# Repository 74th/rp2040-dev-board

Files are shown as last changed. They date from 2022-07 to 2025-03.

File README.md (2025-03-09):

# 74th が RP2040/RP2350 を手ではんだ付けしてみたくて作った開発ボード

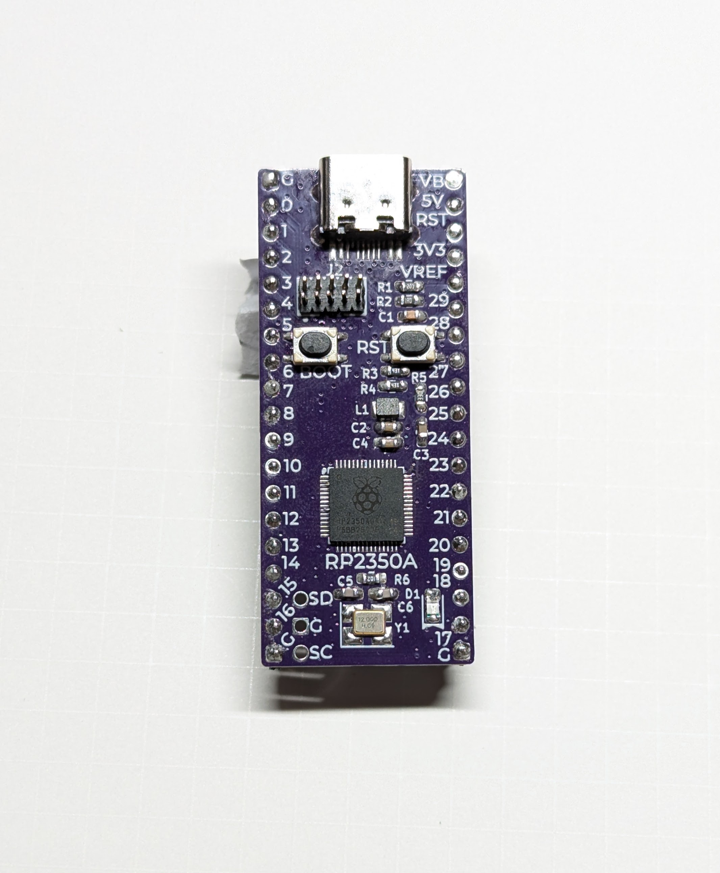
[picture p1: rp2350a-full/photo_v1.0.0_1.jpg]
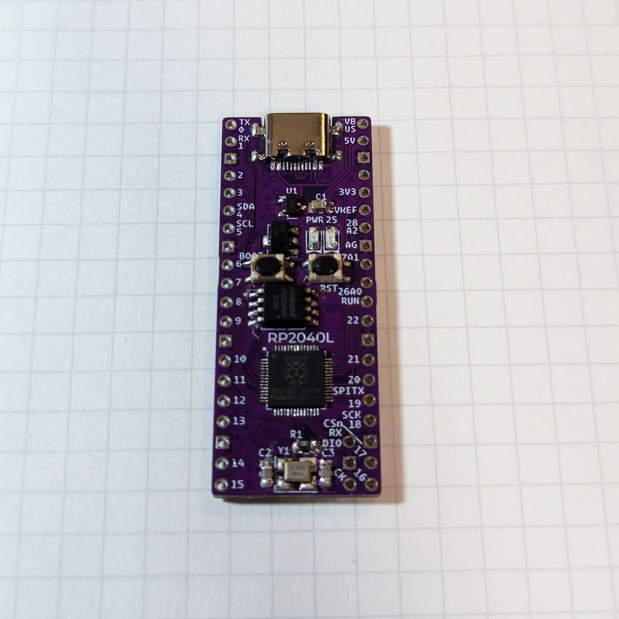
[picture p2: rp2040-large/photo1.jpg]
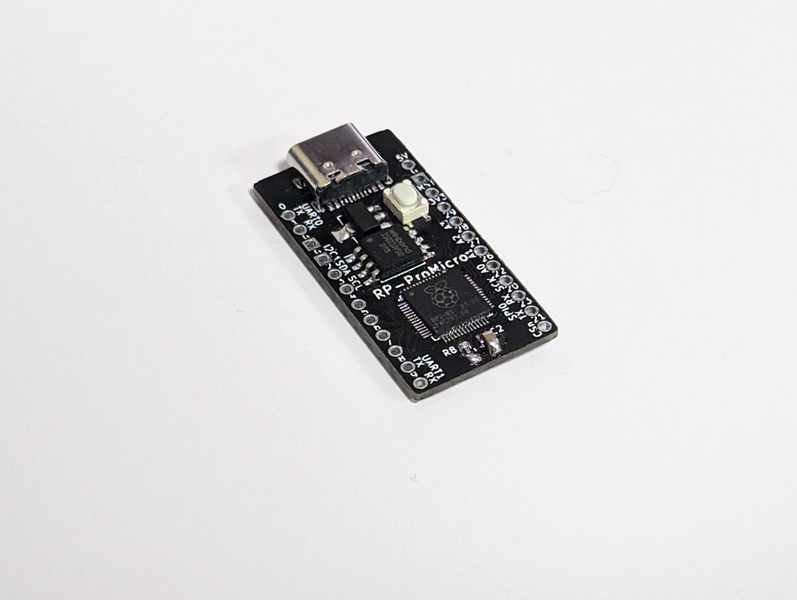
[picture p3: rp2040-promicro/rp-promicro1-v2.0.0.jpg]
  

- [Raspberry PI PICO と同じピン配置で、Flush のサイズを変えたいために、作った開発ボード rp2040 large board](./rp2040-large/)
- [ProMicro ピンアウト開発ボード rp2040 pro micro](./rp2040-promicro/)
- [RP2350の全てのピンを引き足した開発ボード（位置決め治具対応） RP2350A-Full](./rp2350a-full/)
- [RP2040の手はんだ実装支援用位置決め治具 RP2040 Solder Supporter](./rp2040-supporter/)
- [完成後のチェック用に使うファームウェア](rp2040-io-tester/) [rp2040-io-tester.uf2](rp2040-io-tester/rp2040-io-tester.uf2)
- [部品の調達先](./parts/)

## RP2040 手はんだ実装挑戦指南ガイド

74th の実装ノウハウをまとめたガイドを用意しています。初めて挑戦される方はぜひおよみください。

https://docs.google.com/document/d/1oHzV6qEClttqfrnbo-PlUElAemhTQe8-u3ijAKLZYF0/edit#heading=h.1b8zdysibsw9

## 使用しているシンボル、フットプリントライブラリ

https://github.com/74th/my-kicad-parts

## LICENSE

MIT

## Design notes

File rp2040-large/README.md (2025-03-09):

# RP2040 large board

RP2040 を手ではんだづけするのにトライしてみた開発ボードです。

Raspberry Pi PICO と同じピンレイアウトで、Flash を好きなサイズのものに置き換えて使うことができます。

RP2040 の実装の際には、細く切ったマスキングテープを使って位置合わせをしてから、実装すると成功率が上がります。

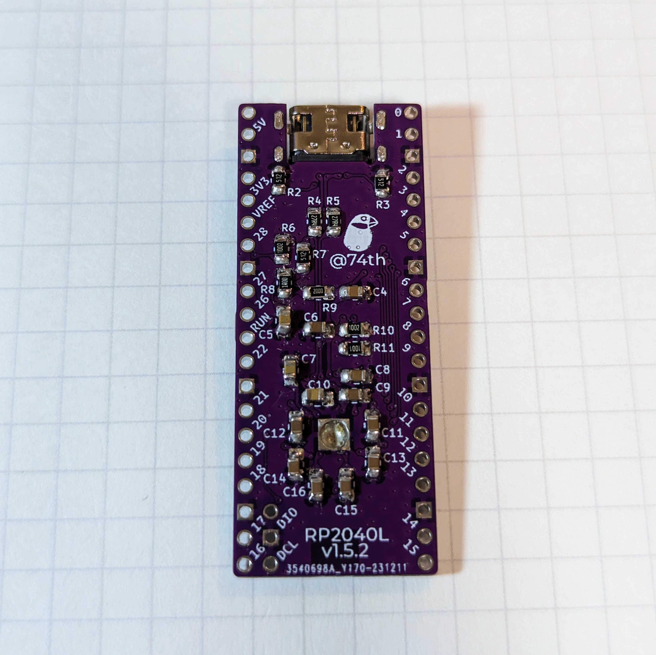
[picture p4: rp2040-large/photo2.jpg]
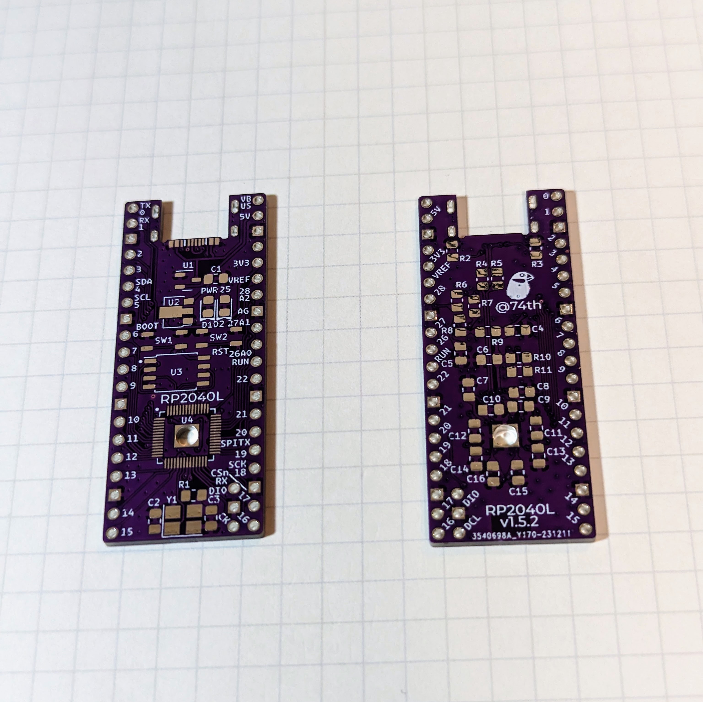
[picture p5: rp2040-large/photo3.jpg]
  

## v1.5.2

- 回路図 [PDF](./rp2040-large-semantics-1.5.2.pdf) [kicanvas](https://kicanvas.org/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)
- PCB [kicanvas](https://kicanvas.org/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)

### features

- USB 電源保護 IC として [CH213K](https://www.wch-ic.com/products/CH213.html) を追加

### BOM

| Reference | Name | Quantity |
| --- | --- | --- |
| C1, C4 | Capacitor 0805 10uF | 2 |
| C2, C3 | Capacitor 0805 10-33pF | 2 |
| C5, C7, C10 | Capacitor 0805 1uF | 3 |
| C6, C8, C9, C11-C16 | Capacitor 0805 100nF | 9 |
| D1 | LED 0805 RED | 1 |
| D2 | LED 0805 BLUE | 1 |
| J1 | USB Type-C Receptacle | 1 |
| R1, R11 | Resistor 0805 1kΩ | 2 |
| R2, R3, R7 | Resistor 0805 5.1kΩ | 3 |
| R4, R5 | Resistor 0805 27Ω | 2 |
| R6, R10 | Resistor 0805 10kΩ | 2 |
| R8 | Resistor 0805 1RΩ | 1 |
| R9 | Resistor 0805 200Ω | 1 |
| SW1, SW2 | Button SKRPABE010 | 2 |
| U1 | USB Power Protection IC SOT-23 CH213K | 1 |
| U2 | Regulator 3.3V SOT-89 AMS1117-3.3 | 1 |
| U3 | Flash SOIC-8 W25Q32JVS | 1 |
| U4 | MCU Raspberry Pi RP2040 | 1 |
| Y1 | Crystal 3225 12MHz | 1 |

### BOM

## v1.4.0

- 回路図 [PDF](./rp2040-large-semantics-1.4.0.pdf) [kicanvas](https://kicanvas.org/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)
- PCB [kicanvas](https://kicanvas.org/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)

| ID | package | Value | Num |
| --- | --- | --- | --- |
| C1,C2,C4,C6-C8,C10,C13,C16 | 0805in 2012mm SMD Capacitor | 100nF | 9 |
| C3,C5,C9 | 0805in 2012mm SMD Capacitor | 1uF | 3 |
| C11,C12 | 0603in 1608mm SMD Capacitor | 27pF | 2 |
| C14,C15 | 0805in 2012mm SMD Capacitor | 10uF | 2 |
| R1,R2 | 0805in 2012mm SMD Resistor | 27.4R | 2 |
| R3,R6 | 0805in 2012mm SMD Resistor | 1kR | 2 |
| R7 | 0805in 2012mm SMD Resistor | 1kR(NC) | 1 |
| R4,R5 | 0805in 2012mm SMD Resistor | 5.1kR | 2 |
| R8 | 0805in 2012mm SMD Resistor | 10kR | 1 |
| R9 | 0805in 2012mm SMD Resistor | 200R | 1 |
| R10 | 0805in 2012mm SMD Resistor | 1R | 1 |
| U1 | RP2040 | | 1 |
| U2 | W25Q32BVSSIG | | 1 |
| U3 | AMS 1117-3.3V | | 1 |
| P1 | USB 2.0 Type-C MidMount Socket | | 1 |
| Y1 | 3325mm SMD Quartz Resonator Crystal | 12MHz | 1 |
| SW1,SW2 | 3x4x2.5mm SMD Tactile Switch | | 2 |

## v1.3.1

| ID | package | Value | Num |
| --- | --- | ----- | --- |
| C1,C2,C4,C6-C8,C10,C13,C16 | 0805in 2012mm SMD Capacitor | 100nF | 9 |
| C3,C5 | 0805in 2012mm SMD Capacitor | 1uF | 2 |
| C11,C12 | 0603in 1608mm SMD Capacitor | 27pF  | 2 |
| C14,C15 | 0805in 2012mm SMD Capacitor | 10uF  | 2 |
| R1,R2 | 0805in 2012mm SMD Resistor | 27.4R | 2 |
| R3,R6,R7 | 0805in 2012mm SMD Resistor | 1kR | 2 |
| R4,R5 | 0805in 2012mm SMD Resistor | 5.1kR | 2 |
| R8 | 0805in 2012mm SMD Resistor | 10kR  | 1 |
| U1 | RP2040 | | 1 |
| U2 | W25Q32BVSSIG | | 1 |
| U3 | AMS 1117-3.3V | | 1 |
| P1 | USB 2.0 Type-C MidMount Socket | | 1 |
| Y1 | 3325mm SMD Quartz Resonator Crystal | 12MHz | 1 |

## 部品の購入先

[../parts/README.md](../parts/README.md)

## RP2040 手はんだ実装挑戦指南ガイド

74th の実装ノウハウをまとめたガイドを用意しています。初めて挑戦される方はぜひおよみください。

https://docs.google.com/document/d/1oHzV6qEClttqfrnbo-PlUElAemhTQe8-u3ijAKLZYF0/edit#heading=h.1b8zdysibsw9

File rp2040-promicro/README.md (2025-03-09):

# RP2040 Pro Micro ピンアウト開発ボード \[74th-012\]

発注用ガーバーファイルは [release page](https://github.com/74th/rp2040-dev-board/releases) を確認ください。

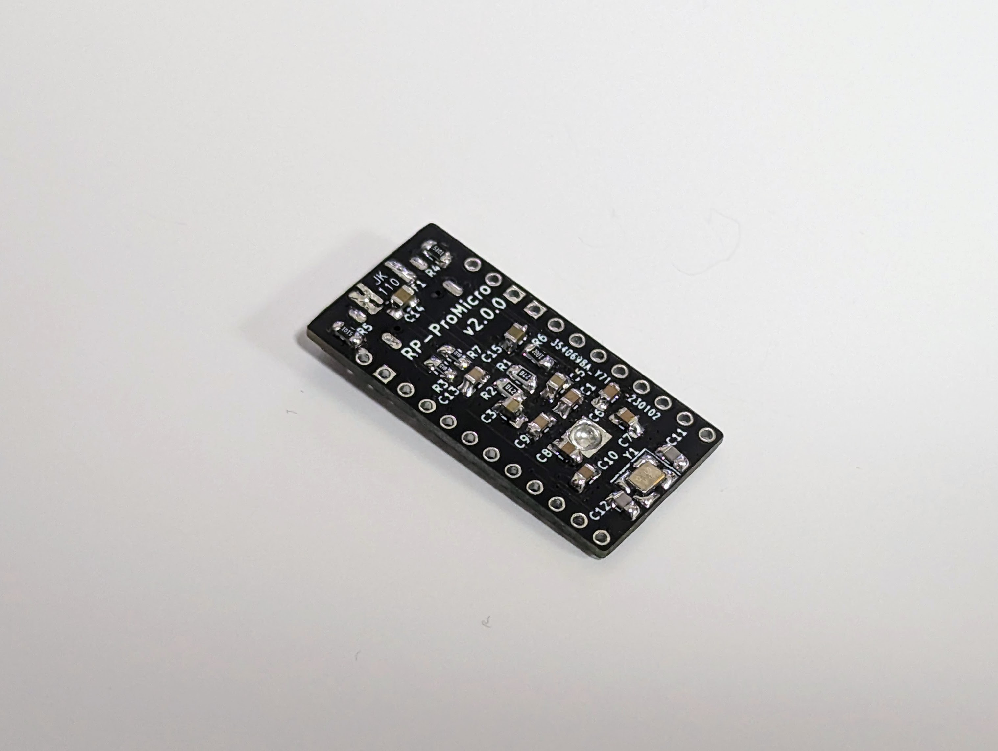
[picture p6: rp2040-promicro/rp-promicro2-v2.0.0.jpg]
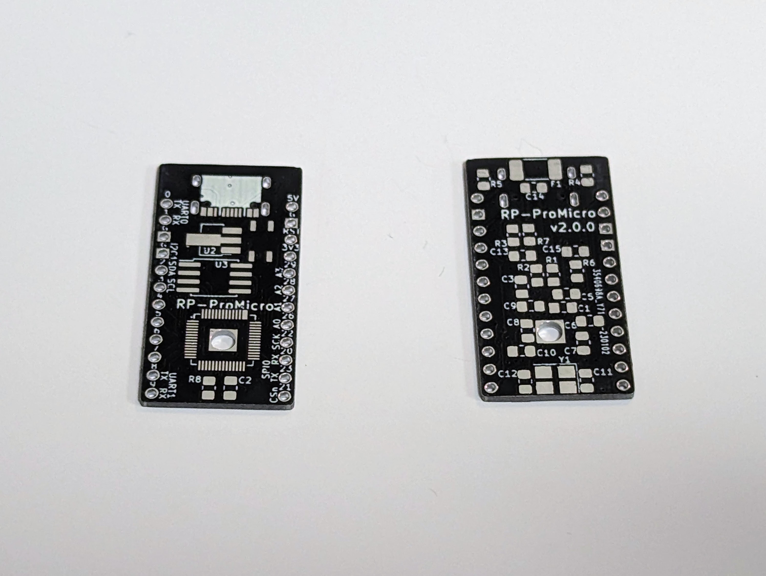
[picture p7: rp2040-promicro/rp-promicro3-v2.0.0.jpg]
  

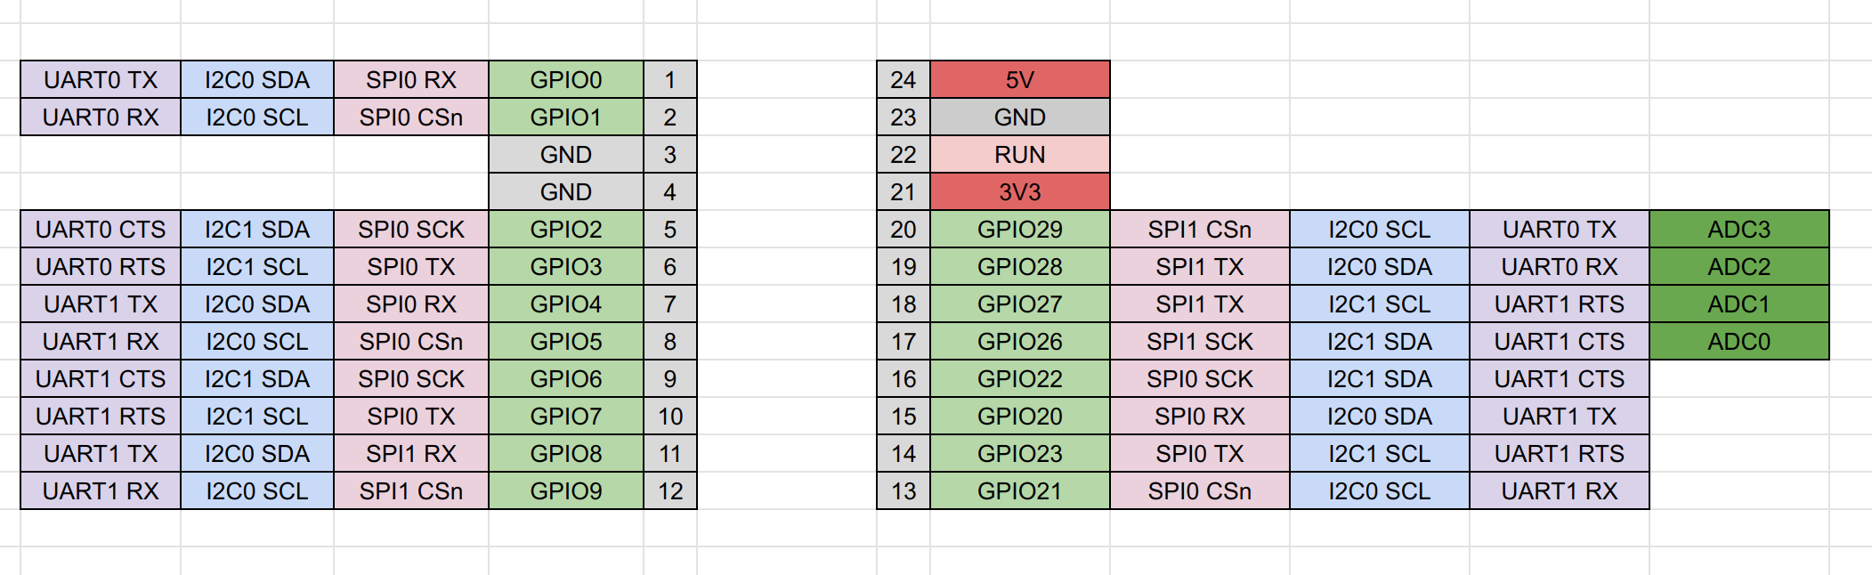
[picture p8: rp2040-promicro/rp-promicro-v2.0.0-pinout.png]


- Booth キット販売ページ [https://74th.booth.pm/items/4492441](https://74th.booth.pm/items/4492441)

## 2.0.1-2

2.0.2 は KiCad 8.0 で出力し直したもので、2.0.1 と差異はありません。

- 回路図: [PDF](rp2040-promicro-v2.0.1-semantics.pdf) [kicanvas](https://kicanvas.org/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)
- PCB 2.0.1 [kicanvas](https://kicanvas.org/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)
- PCB 2.0.2 [kicanvas](https://kicanvas.org/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)

| Reference | Name | Quantity |
| --- | --- | --- |
| C1, C4, C7-C12 | Capacitor 0805 100nF | 8 |
| C2, C3 | Capacitor 0805 10uF | 2 |
| C5, C6 | Capacitor 0805 1uF | 2 |
| C13, C14 | Capacitor 0805 10-27pF | 2 |
| F1 | PolyFuse 1812 KT6-1100SMDI | 1 |
| J1 | USB Type-C Receptacle | 1 |
| R1, R4, R5 | Resistor 0805 1kΩ | 3 |
| R2, R3 | Resistor 0805 5.1kΩ | 2 |
| R6 | Resistor 0805 10kΩ | 1 |
| R7, R8 | Resistor 0805 10-27Ω | 2 |
| SW1 | Button SKRPABE010 | 1 |
| U1 | Regulator 3.3V SOT-89 AMS1117-3.3 | 1 |
| U2 | Flash SOIC-8 W25Q128JVS | 1 |
| U3 | MCU Raspberry Pi RP2040 | 1 |
| Y1 | Crystal 3225 12MHz | 1 |

※ 大変申し訳ありません。2023/09/17 まで誤った部品表が 2.0.1 として掲載されておりました。

## 2.0.0

- 回路図: [PDF](rp2040-promicro-v2.0.0-semantics.pdf) [kicanvas](https://kicanvas.org/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)
- PCB [PDF](rp2040-promicro-v2.0.0-pcb.pdf) [kicanvas](https://kicanvas.org/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)

| Designator | Parts | Quantity |
| --- | --- | --- |
| R1, R2 | 0805 レジスタ 27.4R | 2 |
| R3, R7, R8 | 0805 レジスタ 1kR | 3 |
| R4, R5 | 0805 レジスタ 5.1kR | 2 |
| R6 | 0805 レジスタ 10kR | 1 |
| C1, C2, C6, C7, C8, C9,C10, C13 | 0805 キャパシタ 100nF | 8 |
| C11, C12 | 0805 キャパシタ 27pF | 2 |
| C14, C15 | 0805 キャパシタ 10uF | 2 |
| C3, C5 | 0805 キャパシタ 1uF | 2 |
| F1 | リセッタブルフィーズ KT6-1100SMDI | 1 |
| J1 | USB Type-C ソケット | 1 |
| J2 | ピンヘッダー(ProMicro Left) | 1 |
| J3 | ピンヘッダー(ProMicro Left) | 1 |
| SW1 | SKRPABE010 | 1 |
| U1 | MCU RP2040 | 1 |
| U2 | FLASH W25Q32JVS | 1 |
| U3 | レギュレータ AMS1117(SOT-89) | 1 |
| Y1 | クリスタル 12MHz 3225 | 1 |

## v1.1.0

- 回路図 [rp2040-promicro-v1.1.0-semantics.pdf](rp2040-promicro-v1.1.0-semantics.pdf)
- PCB [rp2040-promicro-v1.1.0-pcb.pdf](rp2040-promicro-v1.1.0-pcb.pdf)

### 部品表

| Item | Qty | Reference(s) | Value | LibPart | Footprint | Datasheet |
| ---- | --- | --- | --- | --- | --- | --- |
| 1 | 9 | C1, C2, C4, C6, C7, C8, C9, C10, C13 | 100nF | Device:C | rp2040-dev-board:Capacitor_0805_2012 | ~ |
| 2 | 2 | C3, C5 | 1uF | Device:C | rp2040-dev-board:Capacitor_0805_2012 | ~ |
| 3 | 2 | C11, C12 | 27pF | Device:C | rp2040-dev-board:Capacitor_0603_1608 | ~ |
| 4 | 2 | C14, C15 | 10uF | Device:C | rp2040-dev-board:Capacitor_0805_2012 | ~ |
| 5 | 1 | J2 | ProMicro-LeftPin  | rp2040-dev-board:ProMicro-LeftPin  | rp2040-dev-board:LeftPin | |
| 6 | 1 | J3 | ProMicro-RightPin | rp2040-dev-board:ProMicro-RightPin | rp2040-dev-board:RightPin | |
| 7 | 1 | P1 | USB2.0_C_12pin | rp2040-dev-board:USB2.0_C_12pin | rp2040-dev-board:USB-C-12-Pin-MidMount-ali-v2 | https://www.usb.org/sites/default/files/documents/usb_type-c.zip |
| 8 | 2 | R1, R2 | 27.4R | Device:R | rp2040-dev-board:Resistor_0805_2012 | ~ |
| 9 | 2 | R3, R7 | 1kR | Device:R | rp2040-dev-board:Resistor_0805_2012 | ~ |
| 10 | 2 | R4, R5 | 5.1kR | Device:R | rp2040-dev-board:Resistor_0805_2012 | ~ |
| 11 | 1 | R6 | 10kR | Device:R | rp2040-dev-board:Resistor_0805_2012 | ~ |
| 12 | 1 | SW1 | SW_Push | Switch:SW_Push | rp2040-dev-board:BOOT | ~ |
| 13 | 1 | U1 | RP2040 | rp2040-dev-board:RP2040 | rp2040-dev-board:RP2040_hand | |
| 14 | 1 | U2 | W25Q128JVS | Memory_Flash:W25Q128JVS | rp2040-dev-board:W25Q16-128JV-SOIC | http://www.winbond.com/resource-files/w25q128jv_dtr%20revc%2003272018%20plus.pdf |
| 15 | 1 | U3 | AZ1117-3.3 | Regulator_Linear:AZ1117-3.3 | rp2040-dev-board:Regulator-AMS1117-SOT-223 | https://www.diodes.com/assets/Datasheets/AZ1117.pdf |
| 16 | 1 | Y1 | Crystal_GND24 | Device:Crystal_GND24 | Crystal:Crystal_SMD_3225-4Pin_3.2x2.5mm_HandSoldering | ~ |

## RP2040 手はんだ実装挑戦指南ガイド

74th の実装ノウハウをまとめたガイドを用意しています。初めて挑戦される方はぜひおよみください。

https://docs.google.com/document/d/1oHzV6qEClttqfrnbo-PlUElAemhTQe8-u3ijAKLZYF0/edit#heading=h.1b8zdysibsw9

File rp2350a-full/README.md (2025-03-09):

# RP2350A 手はんだ実装挑戦ボード

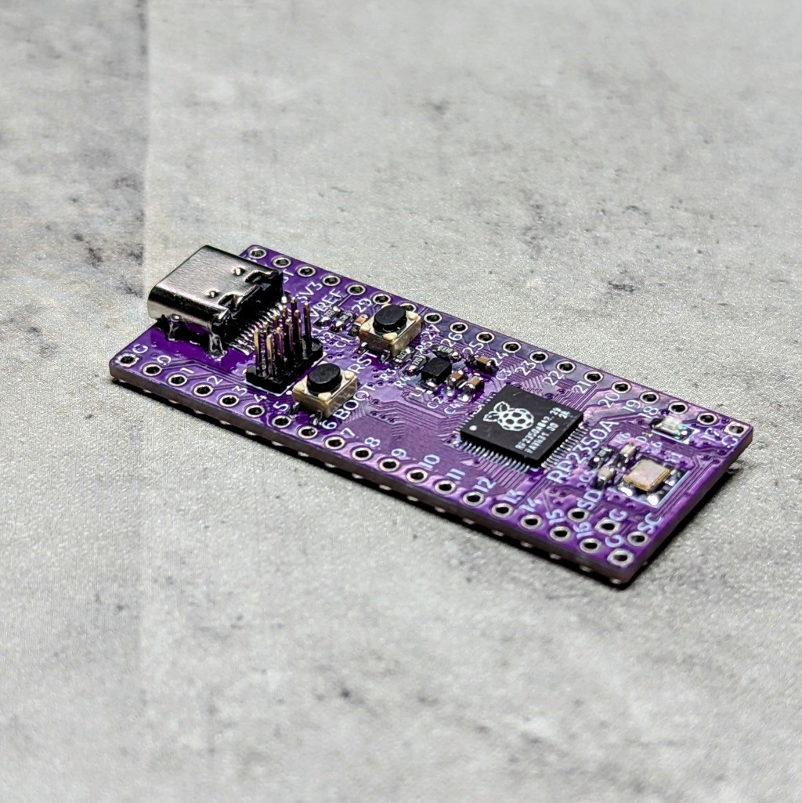
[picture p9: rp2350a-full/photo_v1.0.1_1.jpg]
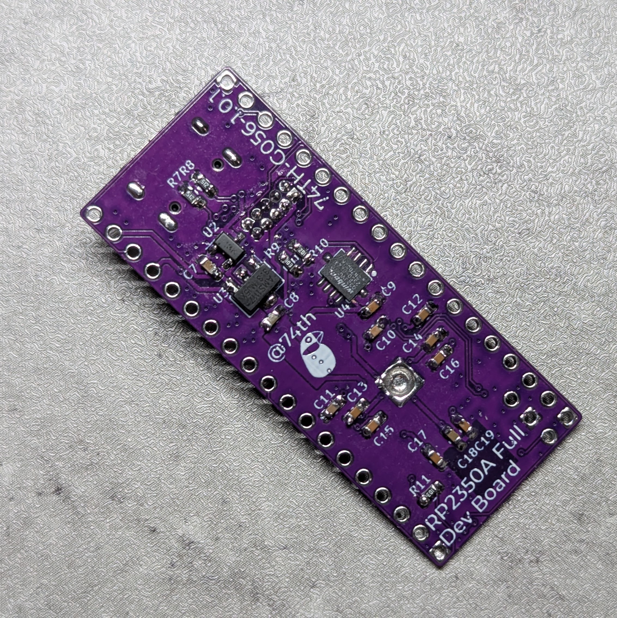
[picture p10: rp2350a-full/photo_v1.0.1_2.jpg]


## v1.0.1

- 回路図 [PDF](./rp2350a-full_v1.0.1_semantics.pdf) [kicanvas](https://kicanvas.org/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)
- PCB [kicanvas](https://kicanvas.org/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)

### Pin Map

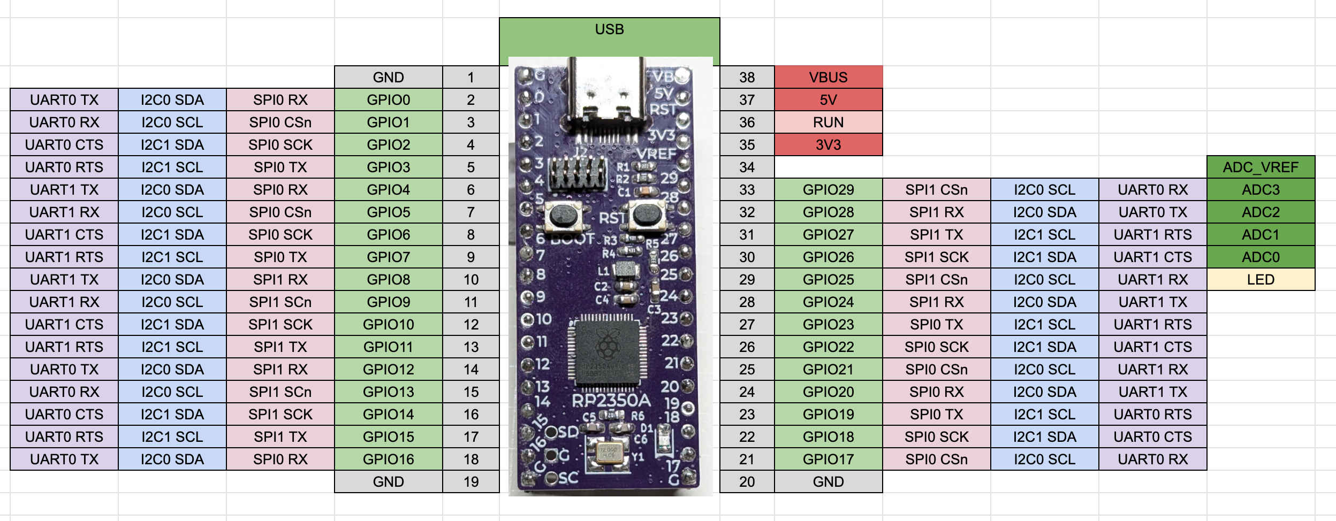
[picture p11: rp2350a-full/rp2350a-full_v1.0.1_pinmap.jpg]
Pin Map


### BOM

| Reference | Name | Package | Quantity |
| --- | --- | --- | --- |
| C1,C9-17,C19 | Capacitor 0.1uF | SMD I0603 M1608 | 11 |
| C2-4,C18 | Capacitor 4.7uF | SMD I0603 M1608 | 4 |
| C5-6 | Capacitor 7-33pF | SMD I0603 M1608 | 2 |
| C7-8 | Capacitor 10uF | SMD I0603 M1608 | 2 |
| D1 | LED Blue | SMD I0805 M2012 | 1 |
| J1 | USB Type-C Receptacle | | 1 |
| J2 | Box Pin Header 2x5 Pitch 1.27mm | TH | 1 |
| L1 | Inductor 3.3uH | SMD I0806 M2016 | 1 |
| R1 | Resistor 200Ω | SMD I0603 M1608 | 1 |
| R2 | Resistor 1Ω | SMD I0603 M1608 | 1 |
| R3-4 | Resistor 27Ω | SMD I0603 M1608 | 2 |
| R5 | Resistor 33Ω | SMD I0603 M1608 | 1 |
| R6,R10 | Resistor 1kΩ | SMD I0603 M1608 | 2 |
| R7-8 | Resistor 5.1kΩ | SMD I0603 M1608 | 2 |
| R9,R11 | Resistor 10kΩ | SMD I0603 M1608 | 2 |
| SW1-2 | Button SKRPABE010 | | 2 |
| U1 | MCU Raspberry Pi RP2350A | QFN56 | 1 |
| U2 | USB Power Protection IC CH213K | SOT-23 | 1 |
| U3 | Regulator 3.3V SOT-89 AMS1117-3.3 | SOT-90 | 1 |
| U4 | Flash W25Q32JVUU | USON-8 | 1 |
| Y1 | Crystal 12MHz | SMD 3225 | 1 |

## 実装の手順

実装したときの記録を記事にしています。こちらを実装前に参考にお読みいただけると良いかと思います。

https://74th.hateblo.jp/entry/2025/01/12/222618

かならずフラックスを用意してください。ブリッジした場合にはフラックスを塗って、はんだごてをあてて余分なフラックスを取り除きましょう。

以下の順序で実装することを推奨しています。

1. RP2350A(U1): RP2040 用の[位置決めボード](https://74th.booth.pm/items/5573498)を使えるなら使いましょう。手はんだ実装時のノウハウは
   https://docs.google.com/document/d/1oHzV6qEClttqfrnbo-PlUElAemhTQe8-u3ijAKLZYF0/edit#heading=h.1b8zdysibsw9 にまとめています。
2. USB Type-C: 受動部品実装前の方が、ランドを用いた疎通チェックがやりやすいため。[実装チェックツール](https://74th.booth.pm/items/5812941)を使うと便利です。
3. DCDC 用インダクタ(L1): 付近に囲むように他の部品があるため、先に実装します。
4. W25Q32VSS(U4): 裏面パッドに流すためのランドがあり、その付近に受動部品があり、後から実装が難しいため。
   - 裏面パッドのランドは他の部分より熱が伝わりにくいです。はんだが吸い込まれるまで、十分に加熱してください。
5. AMS1117-3.3(U3): 近くに CH213 があり、実装しにくいため。
6. CH213(U2)
7. 他の抵抗(R1-11)、キャパシタ(C1-19)、水晶発振器(Y1)、LED(D1)
8. スイッチ(SW1-2): サイズが大きく他の部品の実装の邪魔になるため、後から実装する

確認して実装ミスがなさそうであれば、電気的なチェックに進みましょう。

1. VBUS(VB)、5V、3V3、GND(G)間それぞれの抵抗値を計測し、短絡している（0Ω）となっている事がないことを確認する
2. USB を接続し、5V、3V3 と GND 間の電圧を測り、それぞれの電圧が正常であることを確認する
3. L1 と GND 間の電圧を測り、1.1V が出ていることを確認する。
4. PC に USB が認識されるか確認する。

全てのピンが実装できている稼働を確認するファームウェアを作っています。

各ピンが実装漏れている、若しくはブリッジしているのを確認するファームウェアを作っています。

https://github.com/74th/mcu-pin-check-firmware/

以下がファームウェアへのダイレクトリンクです。

https://github.com/74th/mcu-pin-check-firmware/raw/refs/heads/main/release/rp2350.uf2

GNDとジャンパをつなぎ、開発ボードの各スルーホールにジャンパのもう片方でタッチします。すると、USB CDCにてGPIO 8: L、GPIO 8: Hと出力されます。
これにて、全てのピンが接続され、ブリッジされていないことを確認してください。

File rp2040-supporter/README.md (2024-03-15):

# 汎用 RP2040 手はんだ実装サポート治具

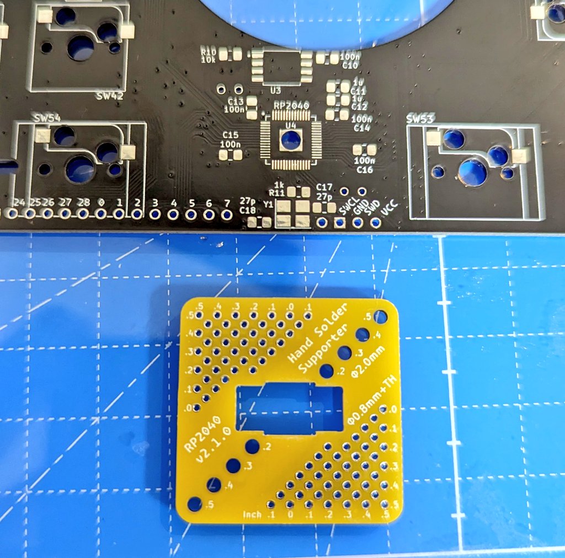
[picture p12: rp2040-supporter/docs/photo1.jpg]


RP2040 を手はんだ実装するときに部品がずれないようにピンヘッダで固定する治具です。

この治具のおかげで、0.4mm ピッチの実装を簡単に行うことができます。

このディレクトリには、使い方の README（このファイル）と、KiCad での設計ファイルが含まれています。

## 使い方

RP2040 のフットプリントは、このリポジトリにある [rp2040-dev-board.pretty/RP2040_hand.kicad_mod](../rp2040-dev-board.pretty/RP2040_hand.kicad_mod) を使用して、裏からサーマルパッドにはんだ付けできるものを利用してください。

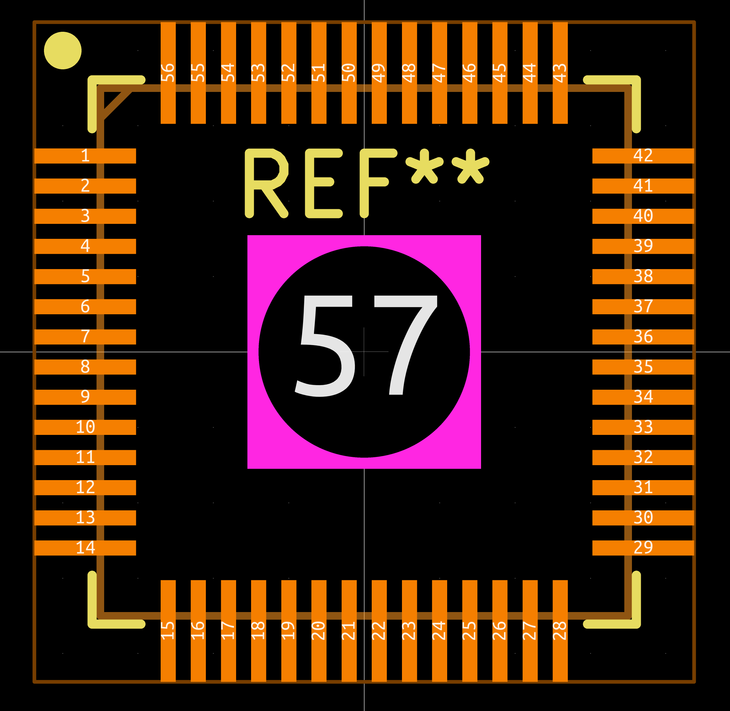
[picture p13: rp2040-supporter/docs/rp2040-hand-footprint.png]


治具には、中心から縦、横それぞれ 0.05 インチ単位で 0.20~0.50 インチ（1.27mm 単位で 5.08mm から 12.70mm）離れたとこにピンヘッダの固定用の穴が空いています。

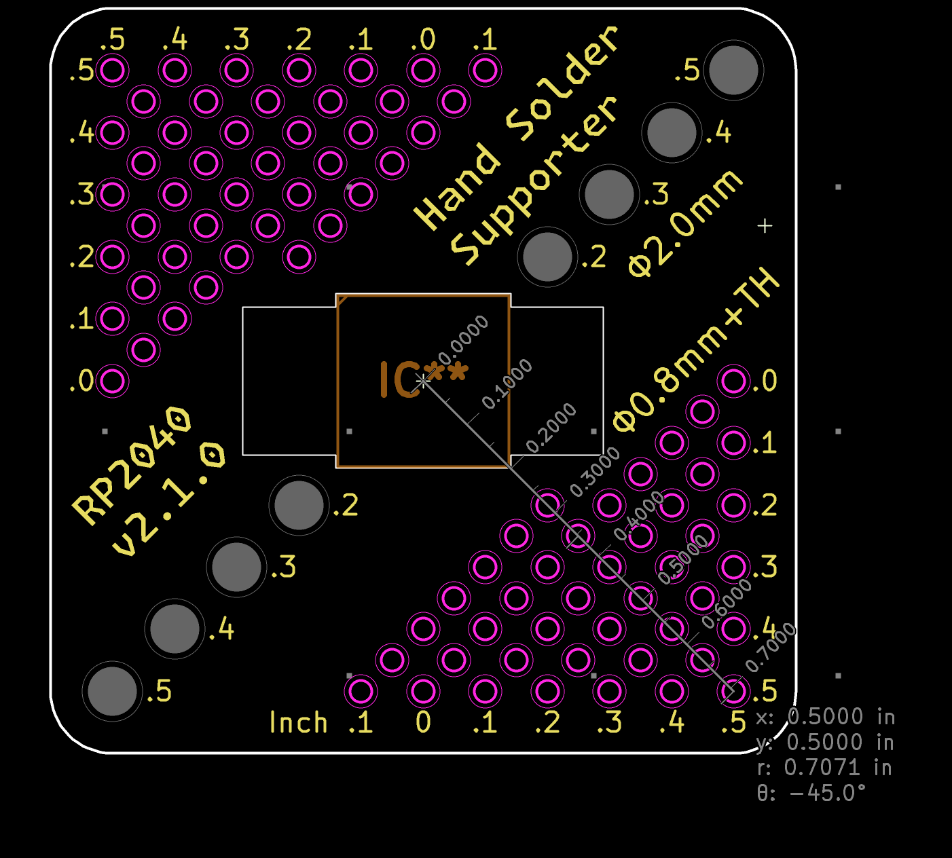
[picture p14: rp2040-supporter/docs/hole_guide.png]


これらの穴を使うように、RP2040 のまわりに 4 点スルーホールを設けます。以下は 1 つの例です。

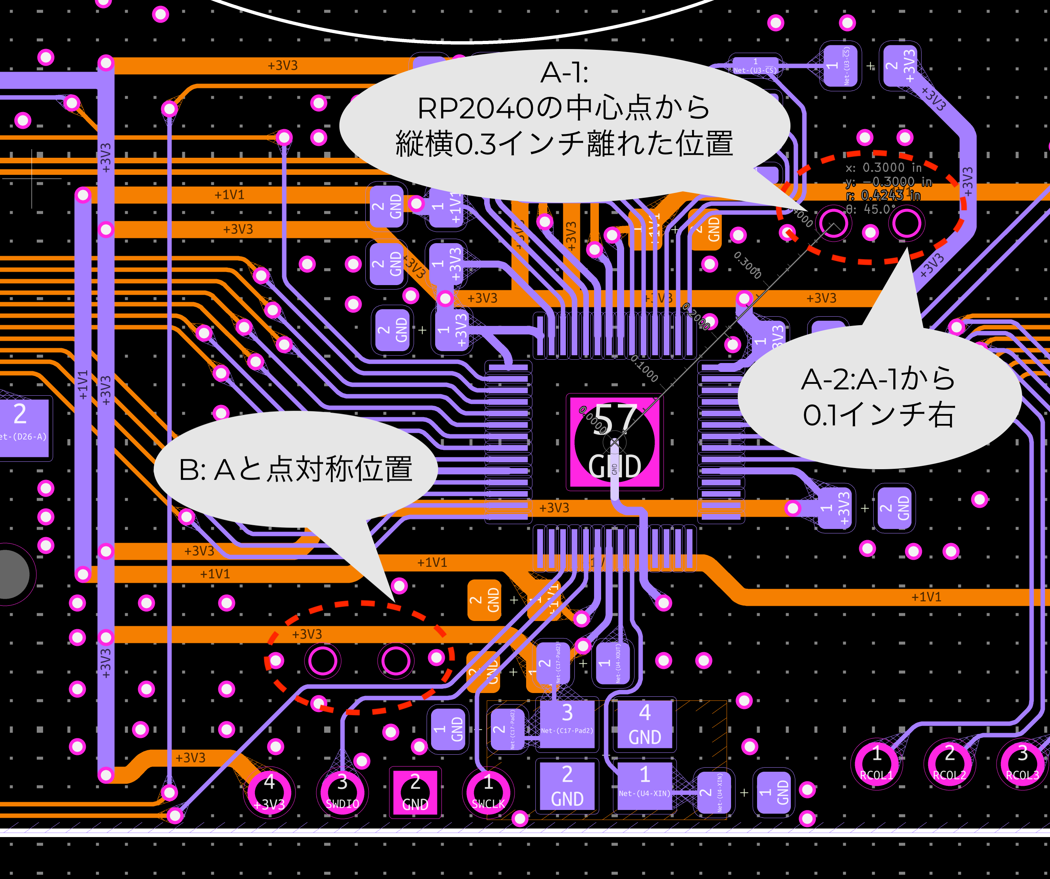
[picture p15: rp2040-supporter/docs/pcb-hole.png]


スルーホールの使用は以下のようにします。

- 穴の直径 0.8mm
- パット直径 1.0mm

実装時には 0.65mm ピンヘッダを通して配置し、RP2040 を治具にセットして、横側だけをはんだ付けします。この時にはブリッジは気にしないではんだ付けしてください。

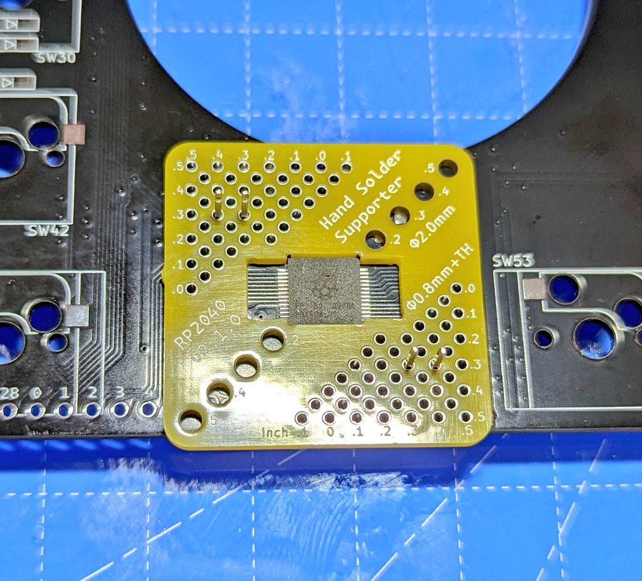
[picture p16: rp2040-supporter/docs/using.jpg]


> [!CAUTION]
> 治具を取り外す時にはかならず RP2040 を押さえつけながら行ってください。無理に外すと、治具が押さえつける力が強くて、パターンごと剥がれる場合があります。

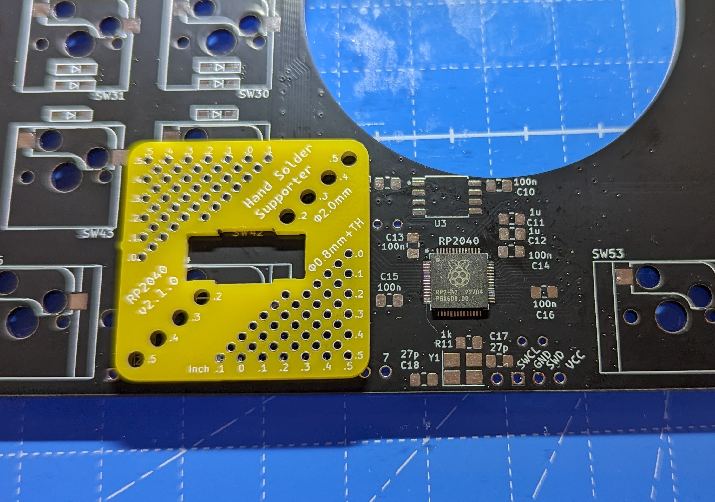
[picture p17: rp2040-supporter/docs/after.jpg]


あとは、フラックスをながしてはんだごてを当てて余分なはんだを取り除いたり、残りのピンを実装したりしてください。

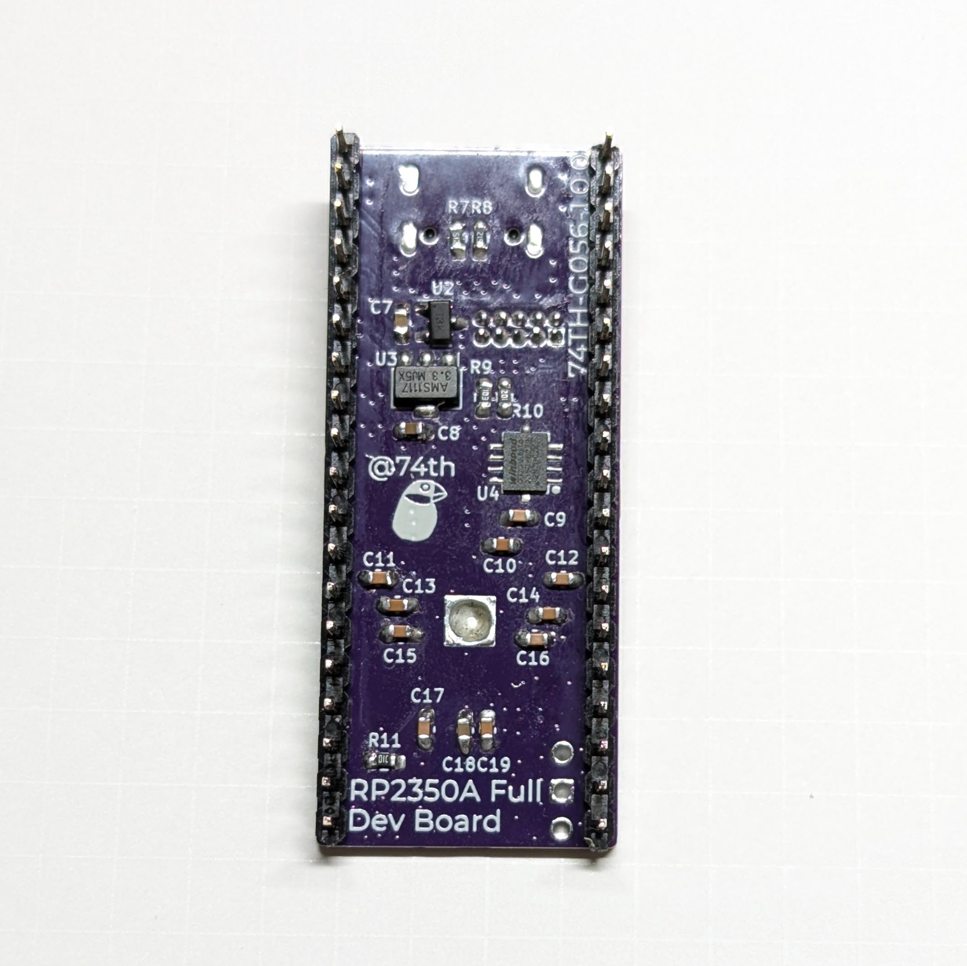
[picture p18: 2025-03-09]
rp2350a-full/photo_v1.0.0_2.jpg

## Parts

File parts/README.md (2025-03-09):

# 部品の調達先

海外サイトですが LCSC で発注をかけた方が、送料はかかりますが、お安くまとまって購入できて便利かもしれません。

☆ 印はキット同梱品の調達先

- RP2040
  - ☆ DigiKey https://www.digikey.jp/ja/products/detail/raspberry-pi/SC0914-7/14306009
  - PIMORONI https://shop.pimoroni.com/products/rp2040?variant=39345229299795
  - スイッチサイエンス https://www.switch-science.com/products/7173
  - マルツオンライン https://www.marutsu.co.jp/pc/i/2230443/
  - 秋月電子通商 https://akizukidenshi.com/catalog/g/g117056/
  - LCSC https://www.lcsc.com/product-detail/C2040.html
- SPI FLASH W25Q32JVSS
  - マルツオンライン https://www.marutsu.co.jp/pc/i/29020236/
  - DigiKey https://www.digikey.jp/ja/products/detail/winbond-electronics/W25Q32JVSSIQ/5803981
  - ☆ LCSC https://www.lcsc.com/product-detail/C179173.html
- SPI FLASH W25Q32JVUU
  - ☆ LCSC https://www.lcsc.com/product-detail/NOR-FLASH_Winbond-Elec-W25Q32JVUUIQ_C2999380.html
- 0805/2012 レジスタ
  - マルツオンライン https://www.marutsu.co.jp/pc/i/856912/
  - TaoBao https://item.taobao.com/item.htm?id=41307854370
  - ☆ LCSC: Package 0805 で絞り込んでください https://www.lcsc.com/products/Chip-Resistor-Surface-Mount_439.html
- 0805/2102 キャパシタ
  - 秋月電子通商 https://akizukidenshi.com/catalog/contents2/capnavi.aspx
  - マルツオンライン https://www.marutsu.co.jp/RatedList.jsp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
  - ☆ LCSC Package 0805 で絞り込んでください https://www.lcsc.com/products/Multilayer-Ceramic-Capacitors-MLCC-SMD-SMT_313.html
  - TaoBao https://item.taobao.com/item.htm?id=522577176099
  - TaoBao https://item.taobao.com/item.htm?id=10191700128
- 3225 クリスタル 12MHz
  - 秋月電子通商 https://akizukidenshi.com/catalog/g/g105225/
  - ☆ LCSC https://www.lcsc.com/product-detail/C9002.html など
  - AliExpress https://ja.aliexpress.com/item/1005002359133404.html
  - TaoBao https://item.taobao.com/item.htm?id=681160536821
- SOT-223 3.3V レギュレータ AMS1117（Pico 型 1.4.0 まで、ProMicro 型 1.1.0 まで）
  - ☆ AliExpress https://ja.aliexpress.com/item/4000187767118.html
  - 秋月電子通商 https://akizukidenshi.com/catalog/g/g111194/
  - LCSC https://www.lcsc.com/product-detail/Linear-Voltage-Regulators-LDO_MSKSEMI-AMS1117-3-3V_C5120796.html
  - ☆ TaoBao https://item.taobao.com/item.htm?id=35642195030
- SOT-89 3.3V レギュレータ AMS1117（Pico 型 1.5.2 以降、ProMicro 型 2.0.0 以降）
  - マルツオンライン https://www.marutsu.co.jp/pc/i/15685944/
  - Aliexpress https://ja.aliexpress.com/item/1005002037850116.html
  - LCSC https://www.lcsc.com/product-detail/C5120796.html
  - ☆ TaoBao https://item.taobao.com/item.htm?id=634687833717
- スイッチ
  - 秋月電子通商 https://akizukidenshi.com/catalog/g/g1006185/
  - ☆ LCSC https://www.lcsc.com/product-detail/C2689510.html
  - TaoBao https://item.taobao.com/item.htm?id=618991813706
  - AliExpress https://ja.aliexpress.com/item/4000555847543.html
- USB Type-C ソケット ミッドマウントタイプ（Pico 型、ProMicro 型 1.1.0 以前）
  - AliExpress https://ja.aliexpress.com/item/32998900371.html
  - マルツオンライン https://www.marutsu.co.jp/pc/i/40730718/
  - LCSC https://www.lcsc.com/product-detail/C428463.html
  - ☆ TaoBao https://item.taobao.com/item.htm?id=619399335978 (TYPEC 母座 16P 4 脚 插板 编带)
- USB Type-C ソケット 表面実装タイプ（ProMicro 型 2.0.0 以降）
  - 秋月電子通商 https://akizukidenshi.com/catalog/g/g114356/
  - LCSC https://www.lcsc.com/product-detail/C2765186.html
  - ☆ TaoBao https://item.taobao.com/item.htm?id=619399335978 (TYPEC 母座 16P 4 脚 插板 编带)
- 1812 6V 1.1A リセッタブルヒューズ（ProMicro 型 2.0.0 以降）
  - マルツオンライン https://www.marutsu.co.jp/pc/i/35540640/
  - LCSC https://www.lcsc.com/product-detail/C210834.html
  - ☆ TaoBao https://item.taobao.com/item.htm?id=555353746767
- CH213K USB 電源保護 IC、理想ダイオード（Pico 型 1.5.2 以降）
  - ☆ Aliexpress WCH Official Shop https://ja.aliexpress.com/item/1005005619632155.html?gatewayAdapt=glo2jpn
  - 秋月電子通商 https://akizukidenshi.com/catalog/g/g129462/
  - TaoBao https://item.taobao.com/item.htm?id=741731017655

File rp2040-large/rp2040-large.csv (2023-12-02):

Reference | Value | Footprint | Function | MPN | 数量
C1, C4 | 10u | 74th:Capacitor_0805_2012 |  |  | 2
C2, C3 | 27p | 74th:Capacitor_0805_2012 |  |  | 2
C5, C7, C10 | 1u | 74th:Capacitor_0805_2012 |  |  | 3
C6, C8, C9, C11-C16 | 100n | 74th:Capacitor_0805_2012 |  |  | 9
CH1 | RasperryPiPico PinOut | 74th:PinOut_RaspberryPiPico |  |  | 1
CH2 | SWD | 74th:PinOut_SWD_3Pin |  |  | 1
D1 | RED | 74th:LED_0805_2012 |  |  | 1
D2 | BLUE | 74th:LED_0805_2012 |  |  | 1
J1 | 217179-0001 | 74th:Connector_USB-C-Receptacle_SMT_12-Pin_MidMount_Simple |  |  | 1
R1, R11 | 1k | 74th:Register_0805_2012 |  |  | 2
R2, R3, R7 | 5.1k | 74th:Register_0805_2012 |  |  | 3
R4, R5 | 27.4 | 74th:Register_0805_2012 |  |  | 2
R6, R10 | 10k | 74th:Register_0805_2012 |  |  | 2
R8 | 1R | 74th:Register_0805_2012 |  |  | 1
R9 | 200 | 74th:Register_0805_2012 |  |  | 1
SW1, SW2 | SW_Push | 74th:PushButton_SKRPABE010 | -- ミックスされた値 -- |  | 2
U1 | CH213K | 74th:Package_SOT-23 |  |  | 1
U2 | AMS1117-3.3 | 74th:Package_SOT-89-3 |  |  | 1
U3 | W25Q32JVS | 74th:Package_SOIC-8_5.23x5.23mm_P1.27mm |  |  | 1
U4 | RP2040 | 74th:Package_QFN-54-1EP_7x7mm_P0.4mm_EP3.1x3.1mm_hand |  | C2040 | 1
Y1 | 12M | 74th:Crystal_SMD_3225-4Pin_3.2x2.5mm_HandSoldering |  |  | 1

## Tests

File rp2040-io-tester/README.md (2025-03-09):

GND を各ピンをつなぐと、USB CBC 経由で、どのピンに触ったかがわかって、IO の確認ができるファームウェア。

以下のリポジトリに移動しました。

https://github.com/74th/mcu-pin-check-firmware

https://github.com/74th/mcu-pin-check-firmware/tree/main/rp2040

https://github.com/74th/mcu-pin-check-firmware/blob/main/release/rp2040.uf2

https://github.com/74th/mcu-pin-check-firmware/tree/main/rp2350

https://github.com/74th/mcu-pin-check-firmware/blob/main/release/rp2350.uf2

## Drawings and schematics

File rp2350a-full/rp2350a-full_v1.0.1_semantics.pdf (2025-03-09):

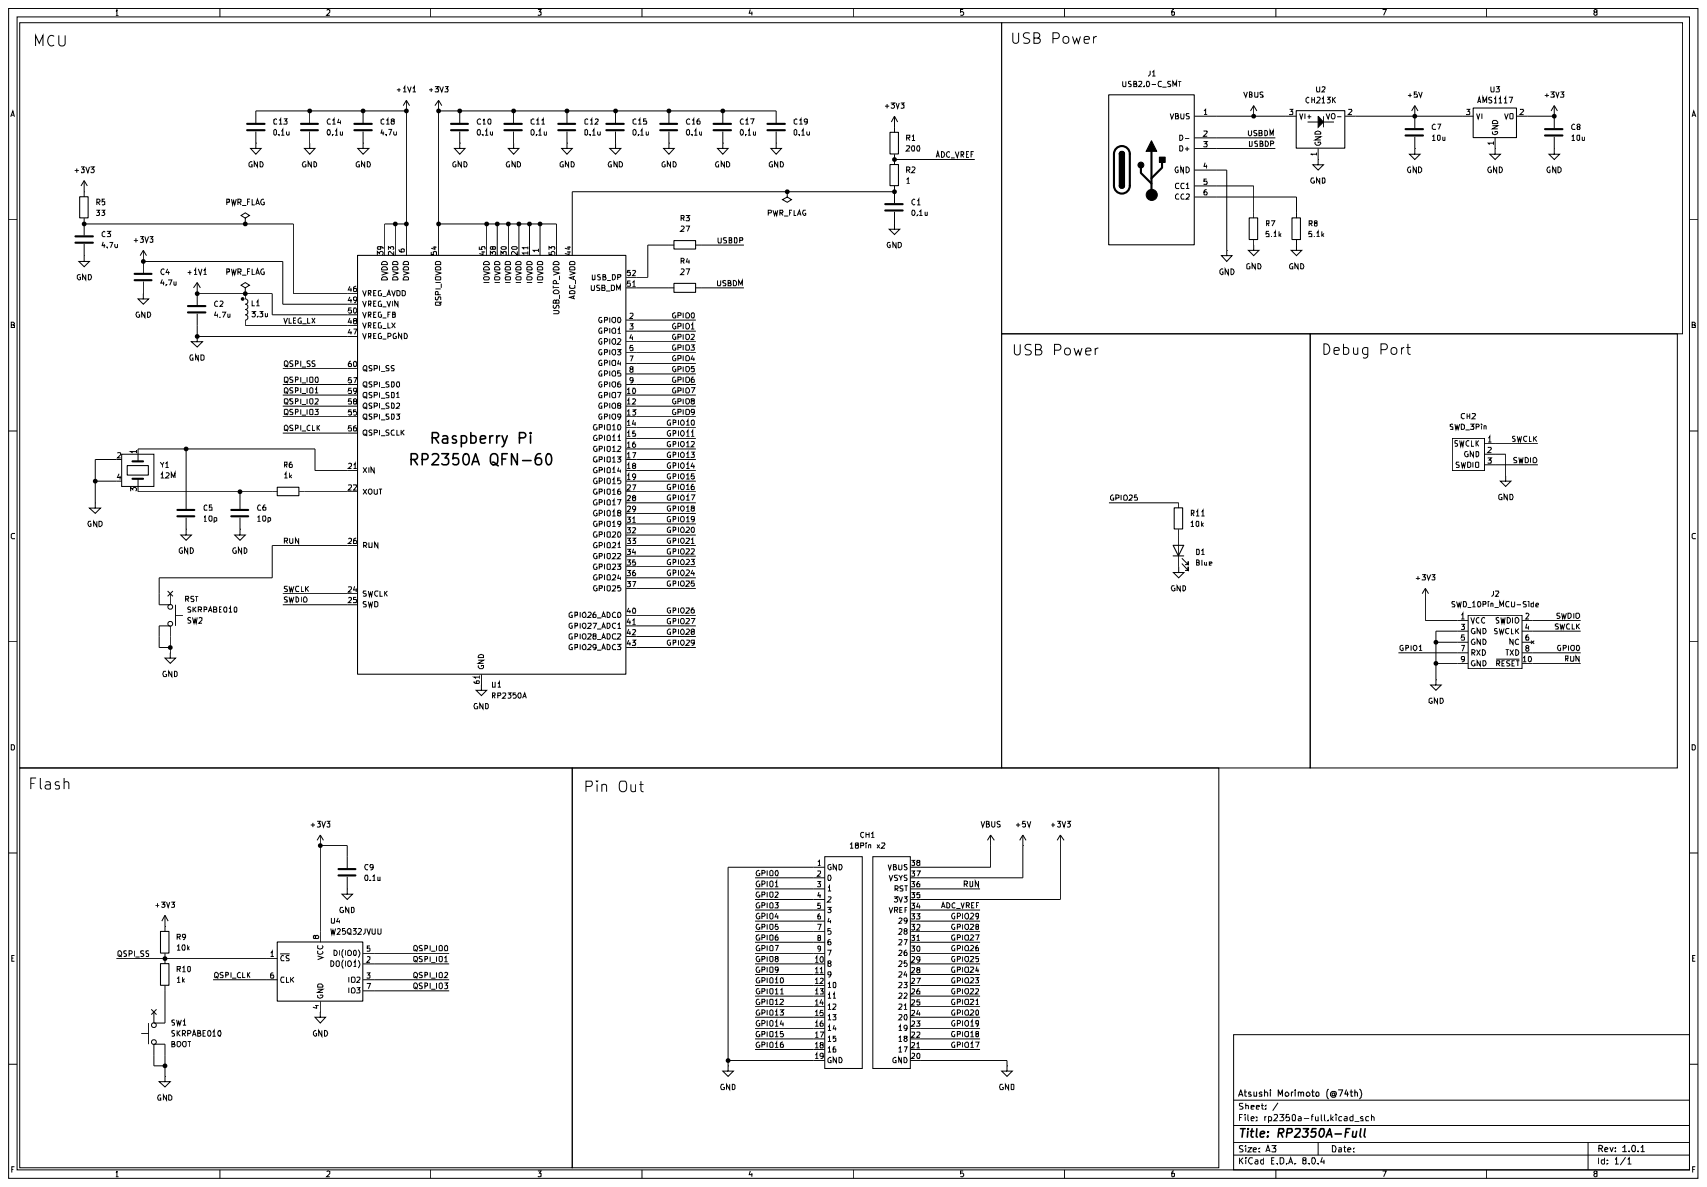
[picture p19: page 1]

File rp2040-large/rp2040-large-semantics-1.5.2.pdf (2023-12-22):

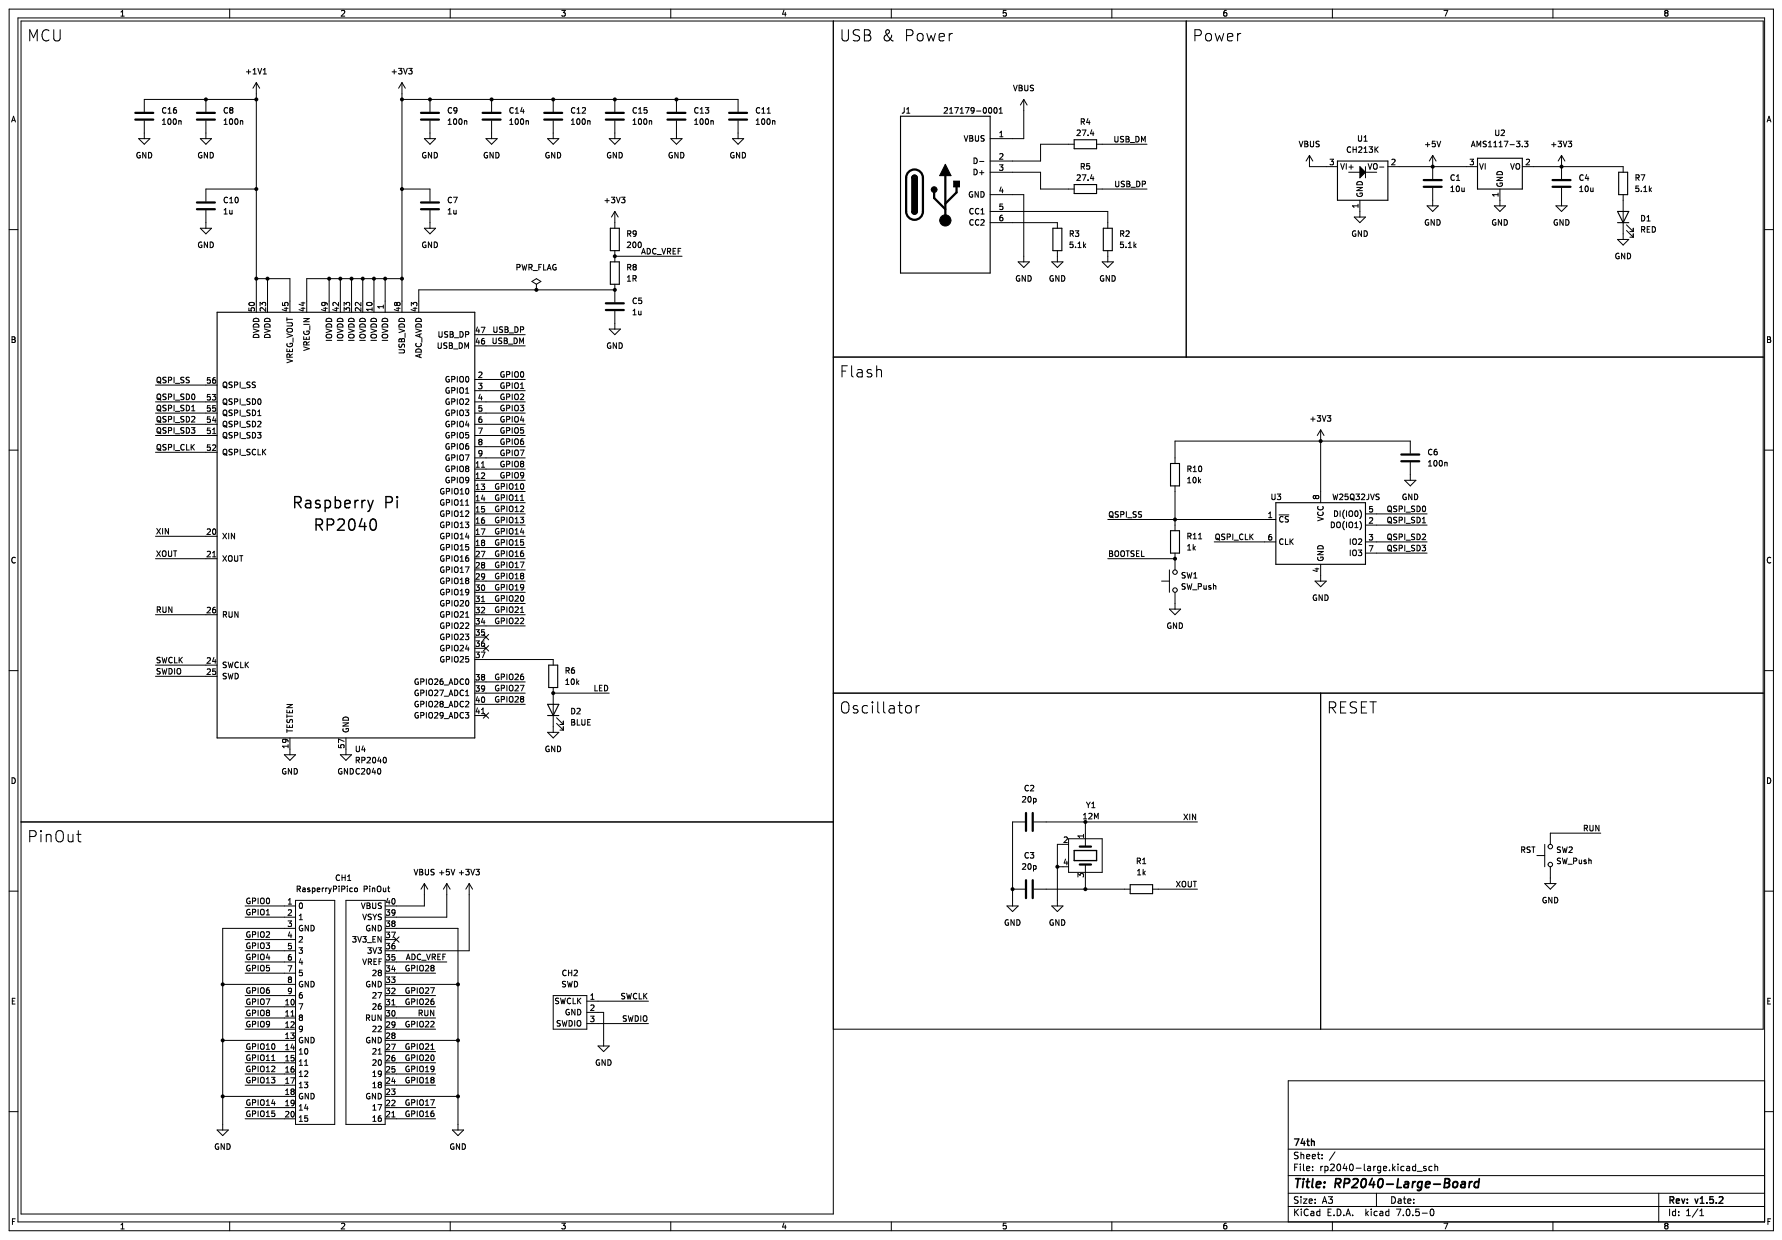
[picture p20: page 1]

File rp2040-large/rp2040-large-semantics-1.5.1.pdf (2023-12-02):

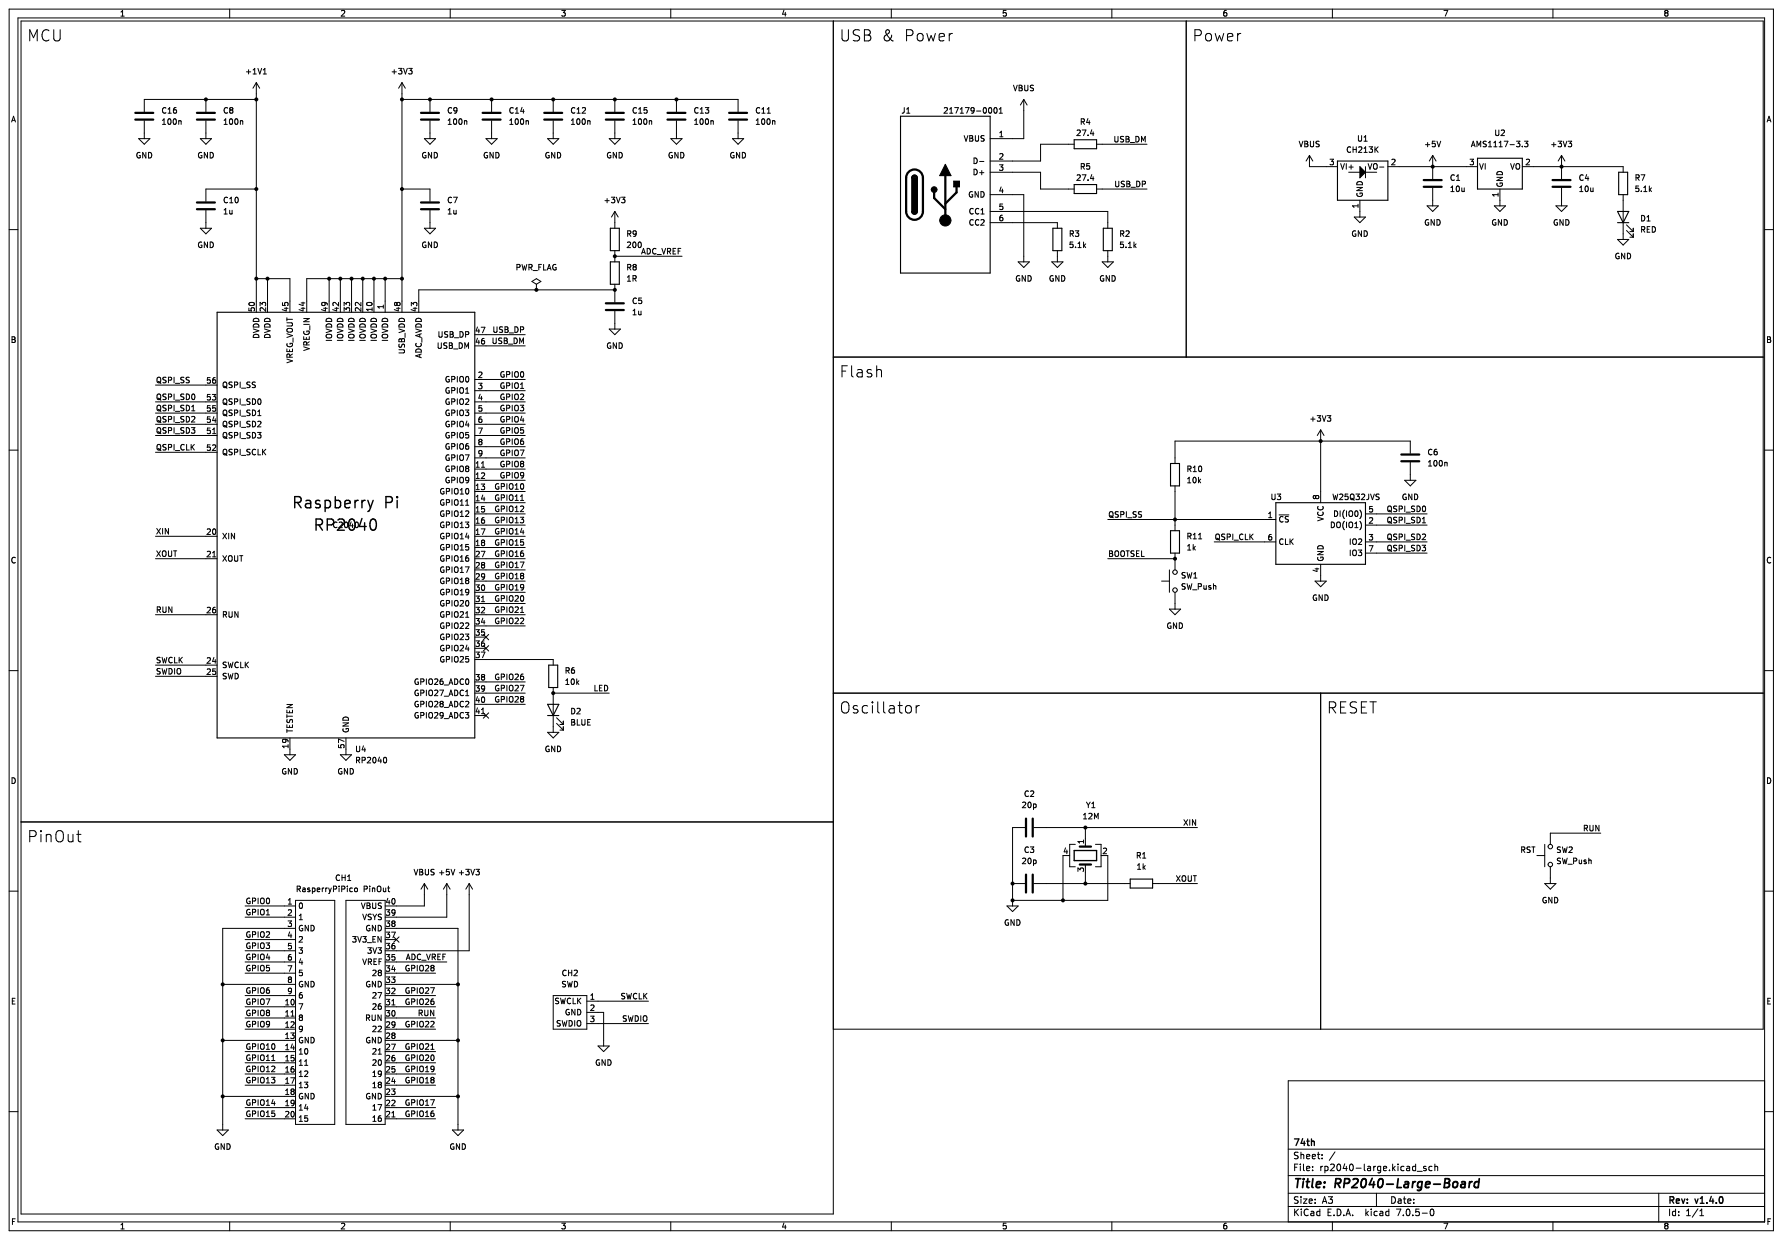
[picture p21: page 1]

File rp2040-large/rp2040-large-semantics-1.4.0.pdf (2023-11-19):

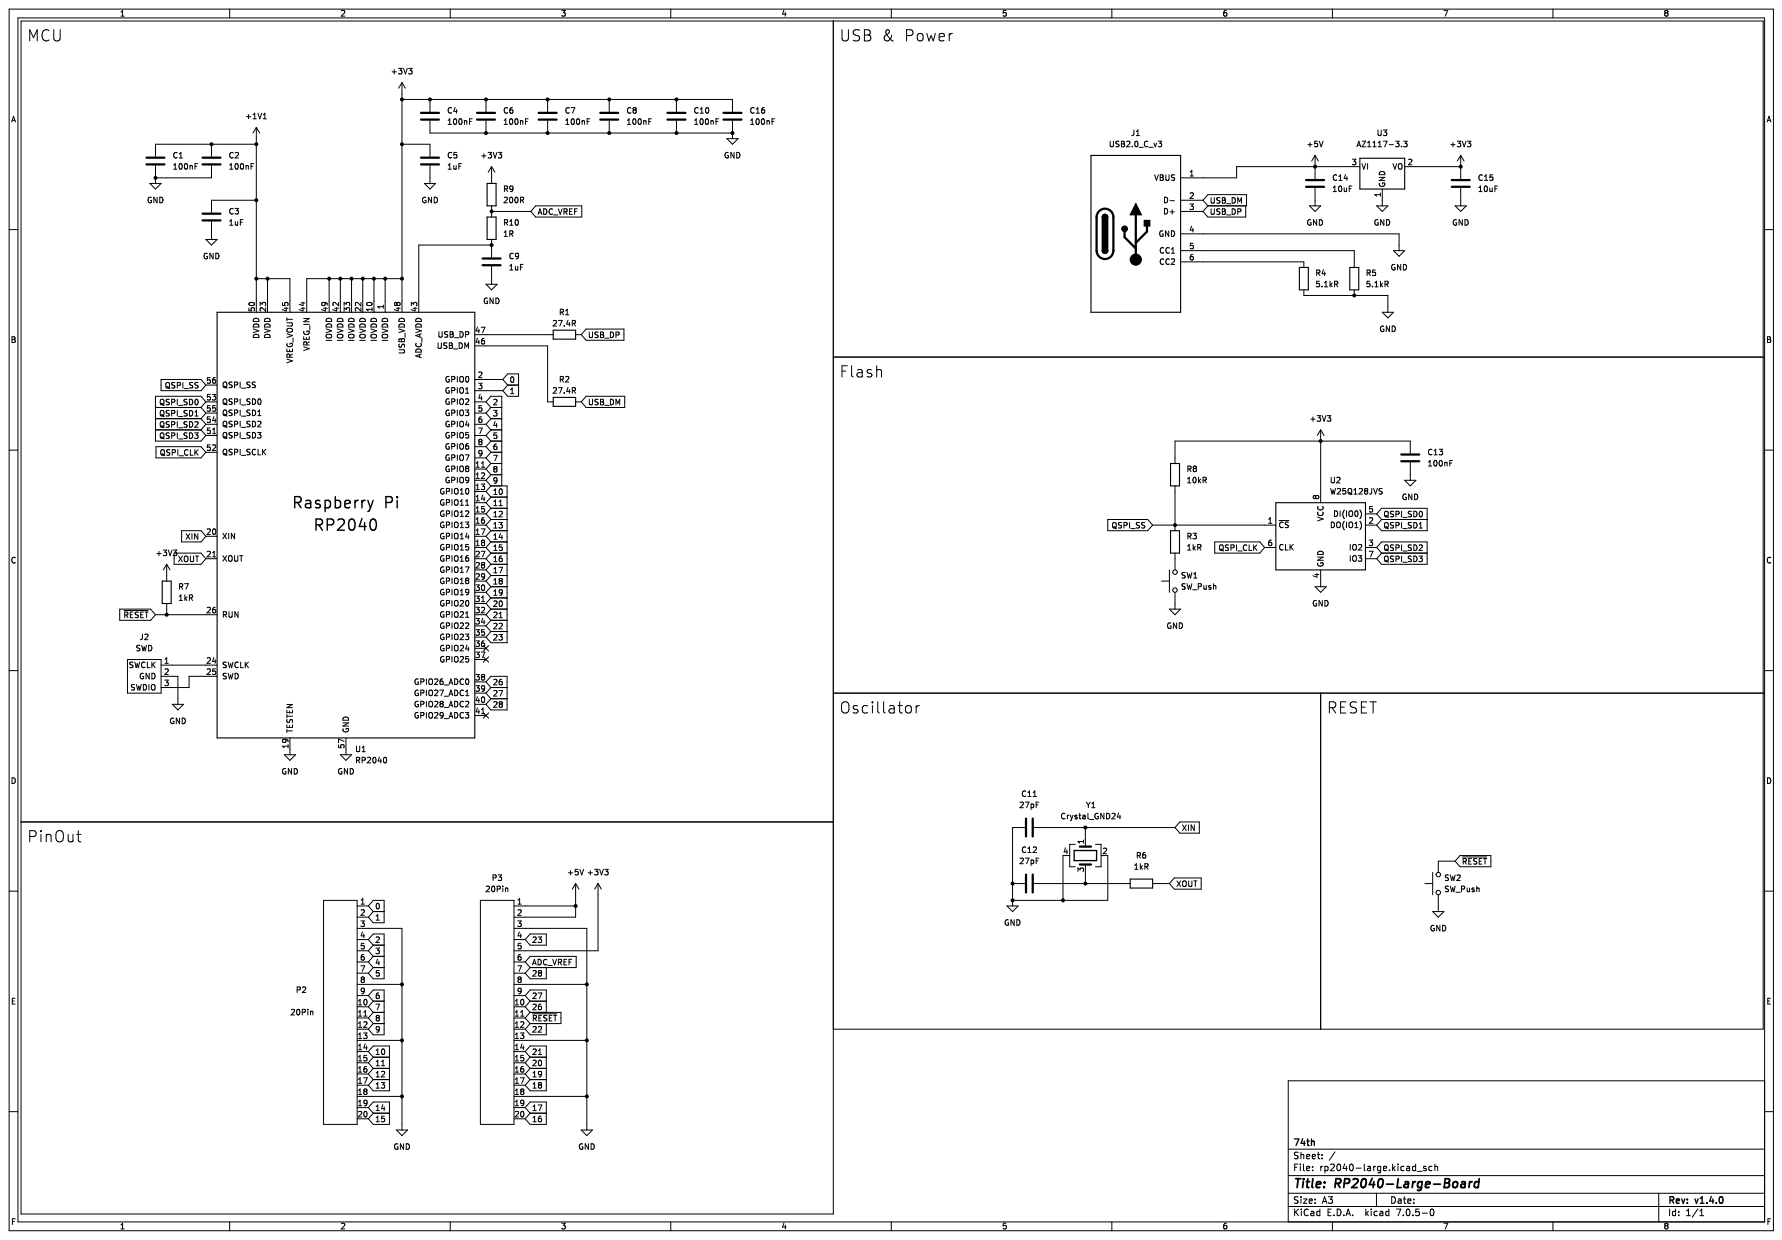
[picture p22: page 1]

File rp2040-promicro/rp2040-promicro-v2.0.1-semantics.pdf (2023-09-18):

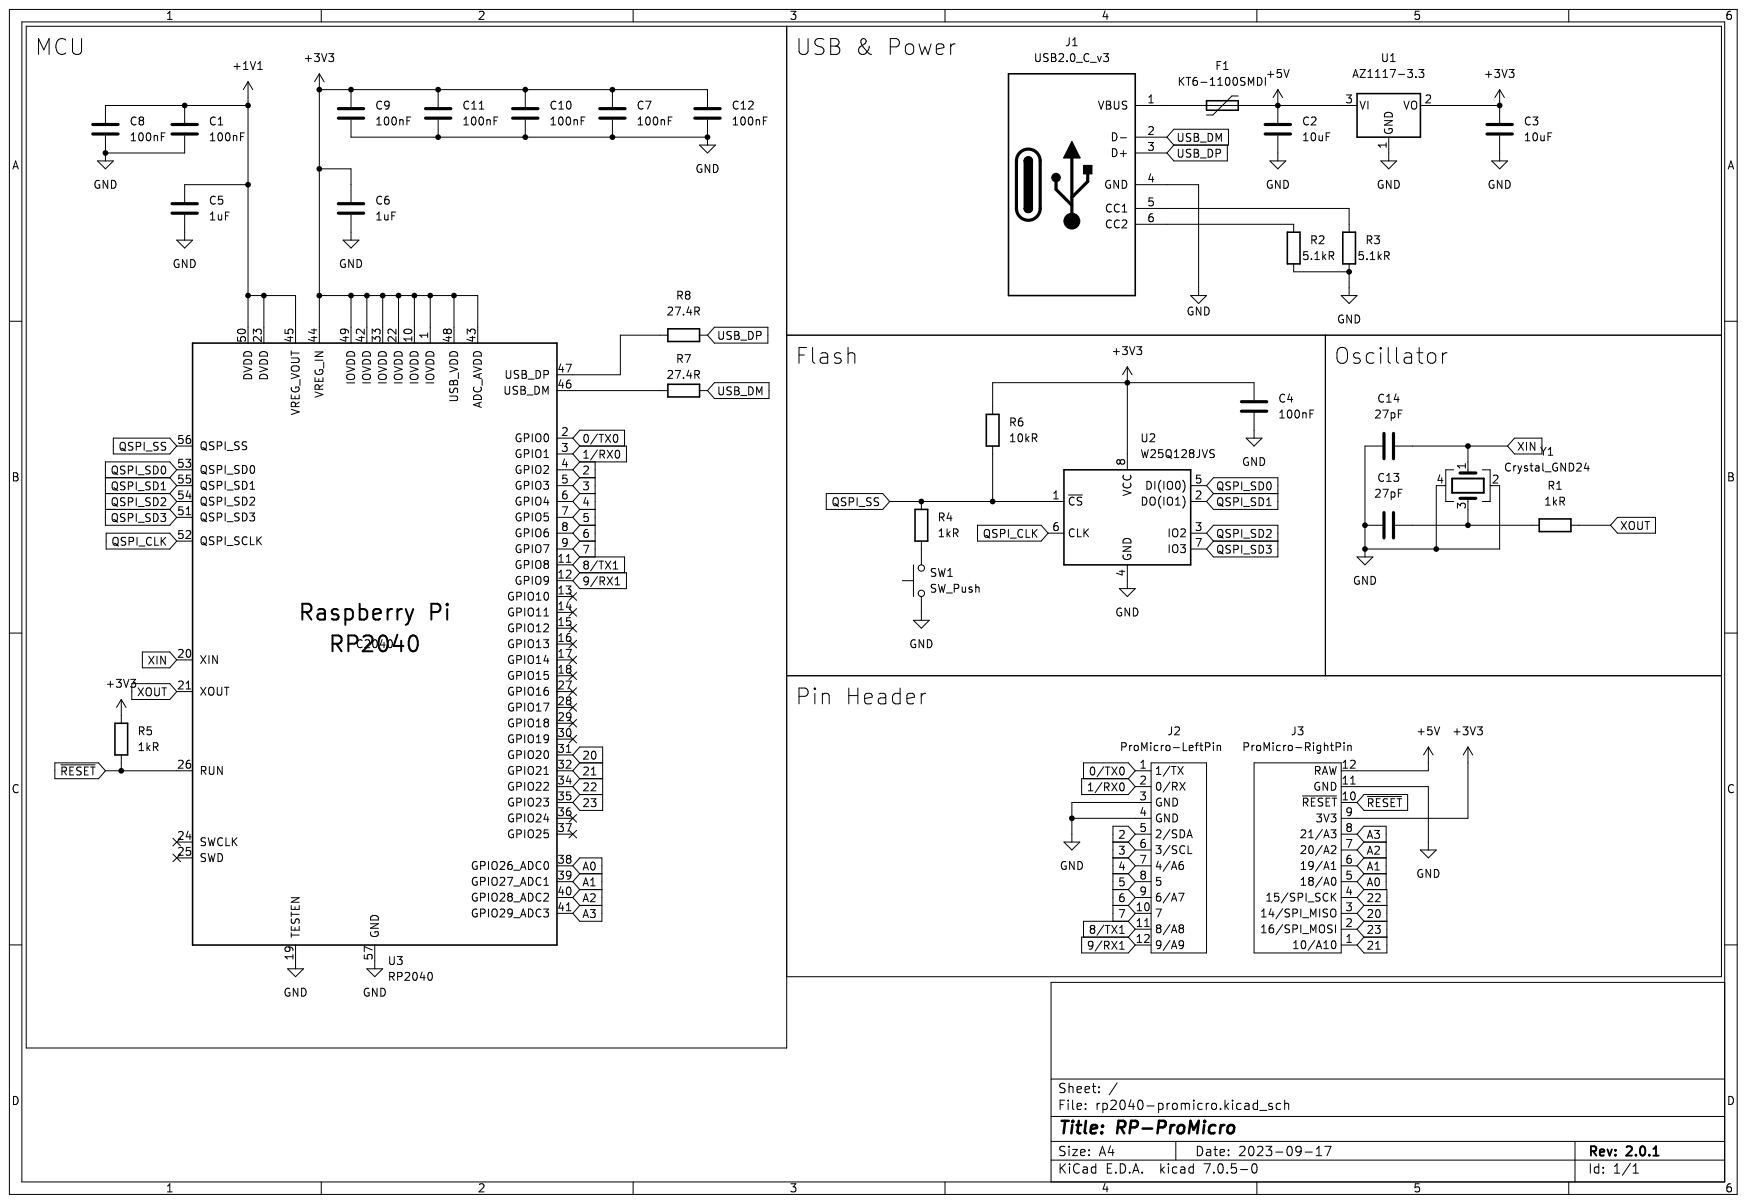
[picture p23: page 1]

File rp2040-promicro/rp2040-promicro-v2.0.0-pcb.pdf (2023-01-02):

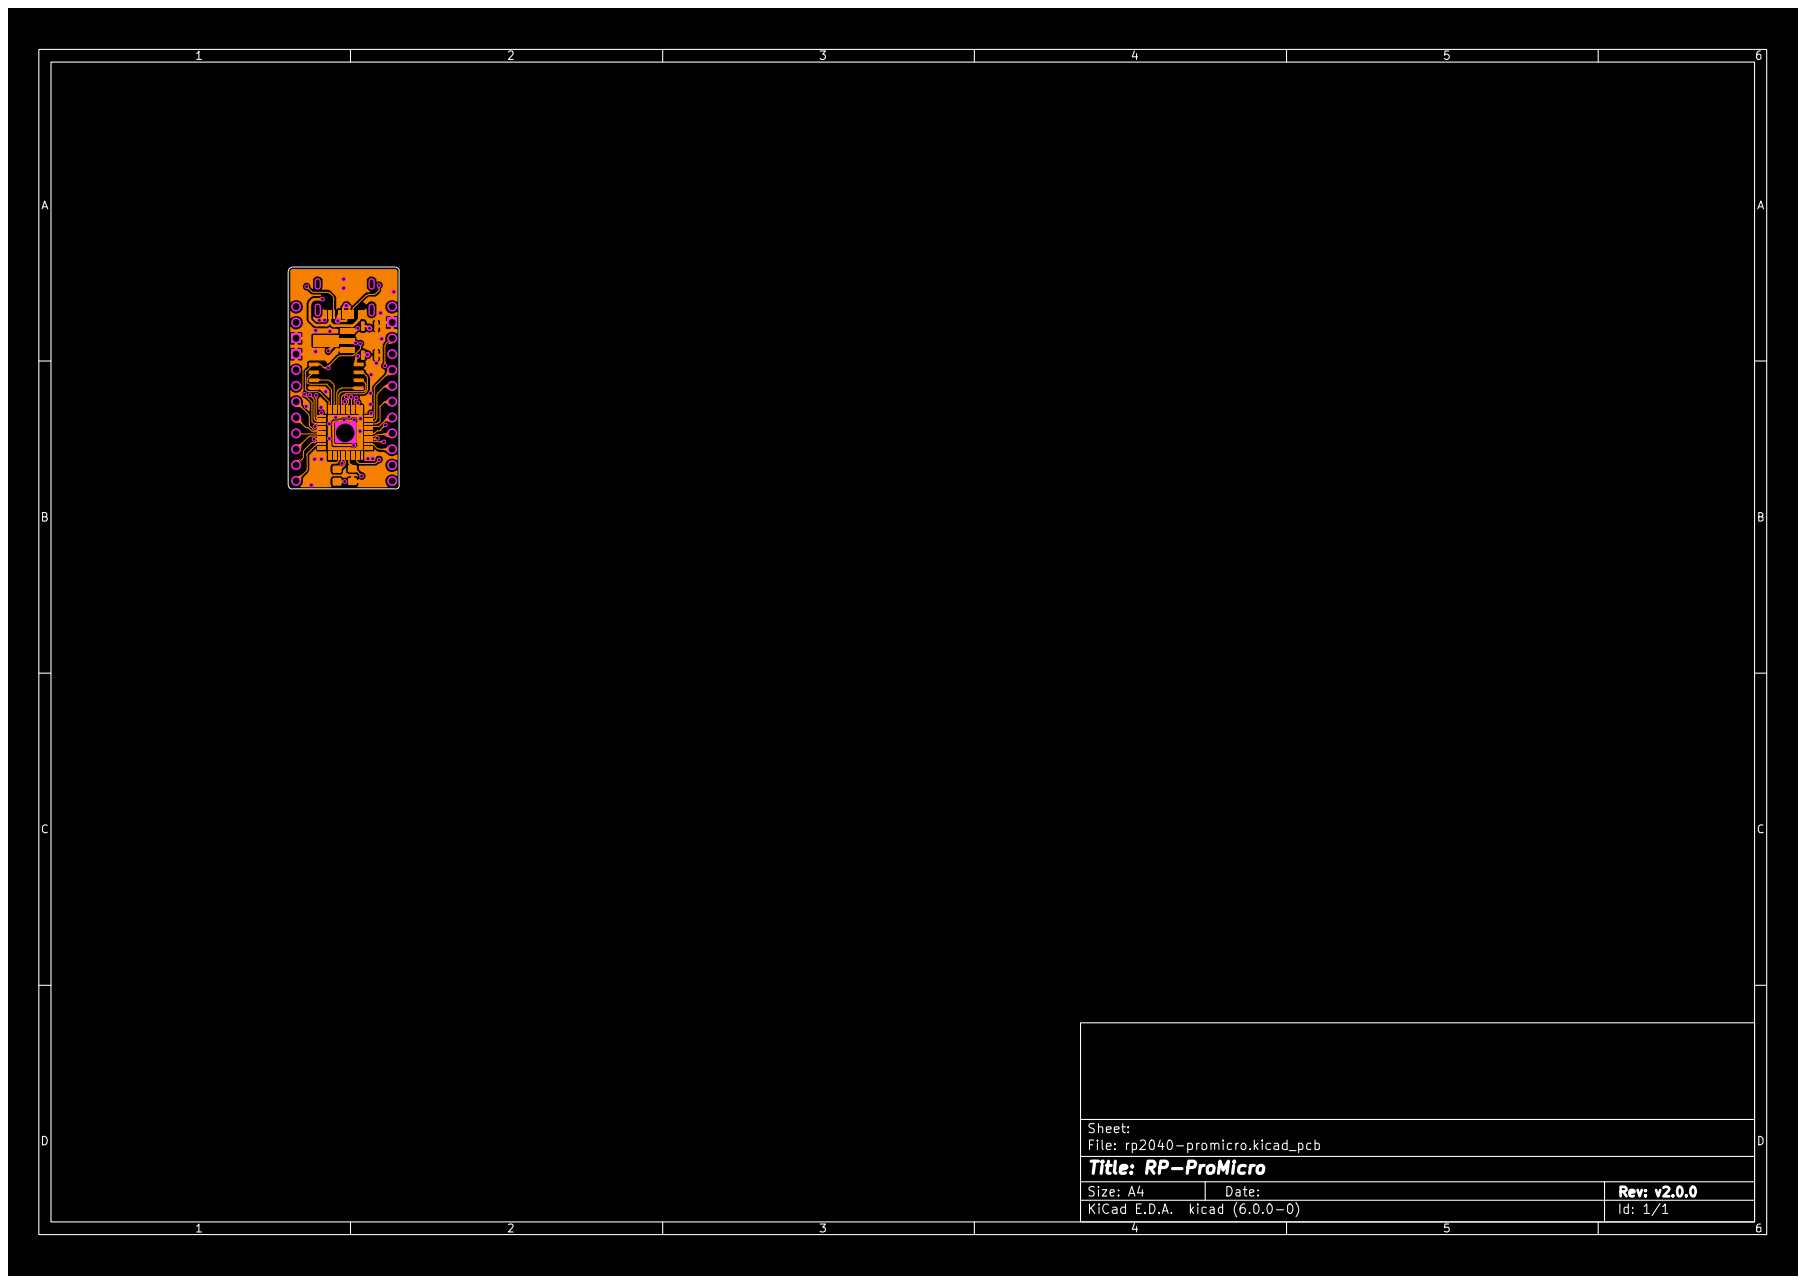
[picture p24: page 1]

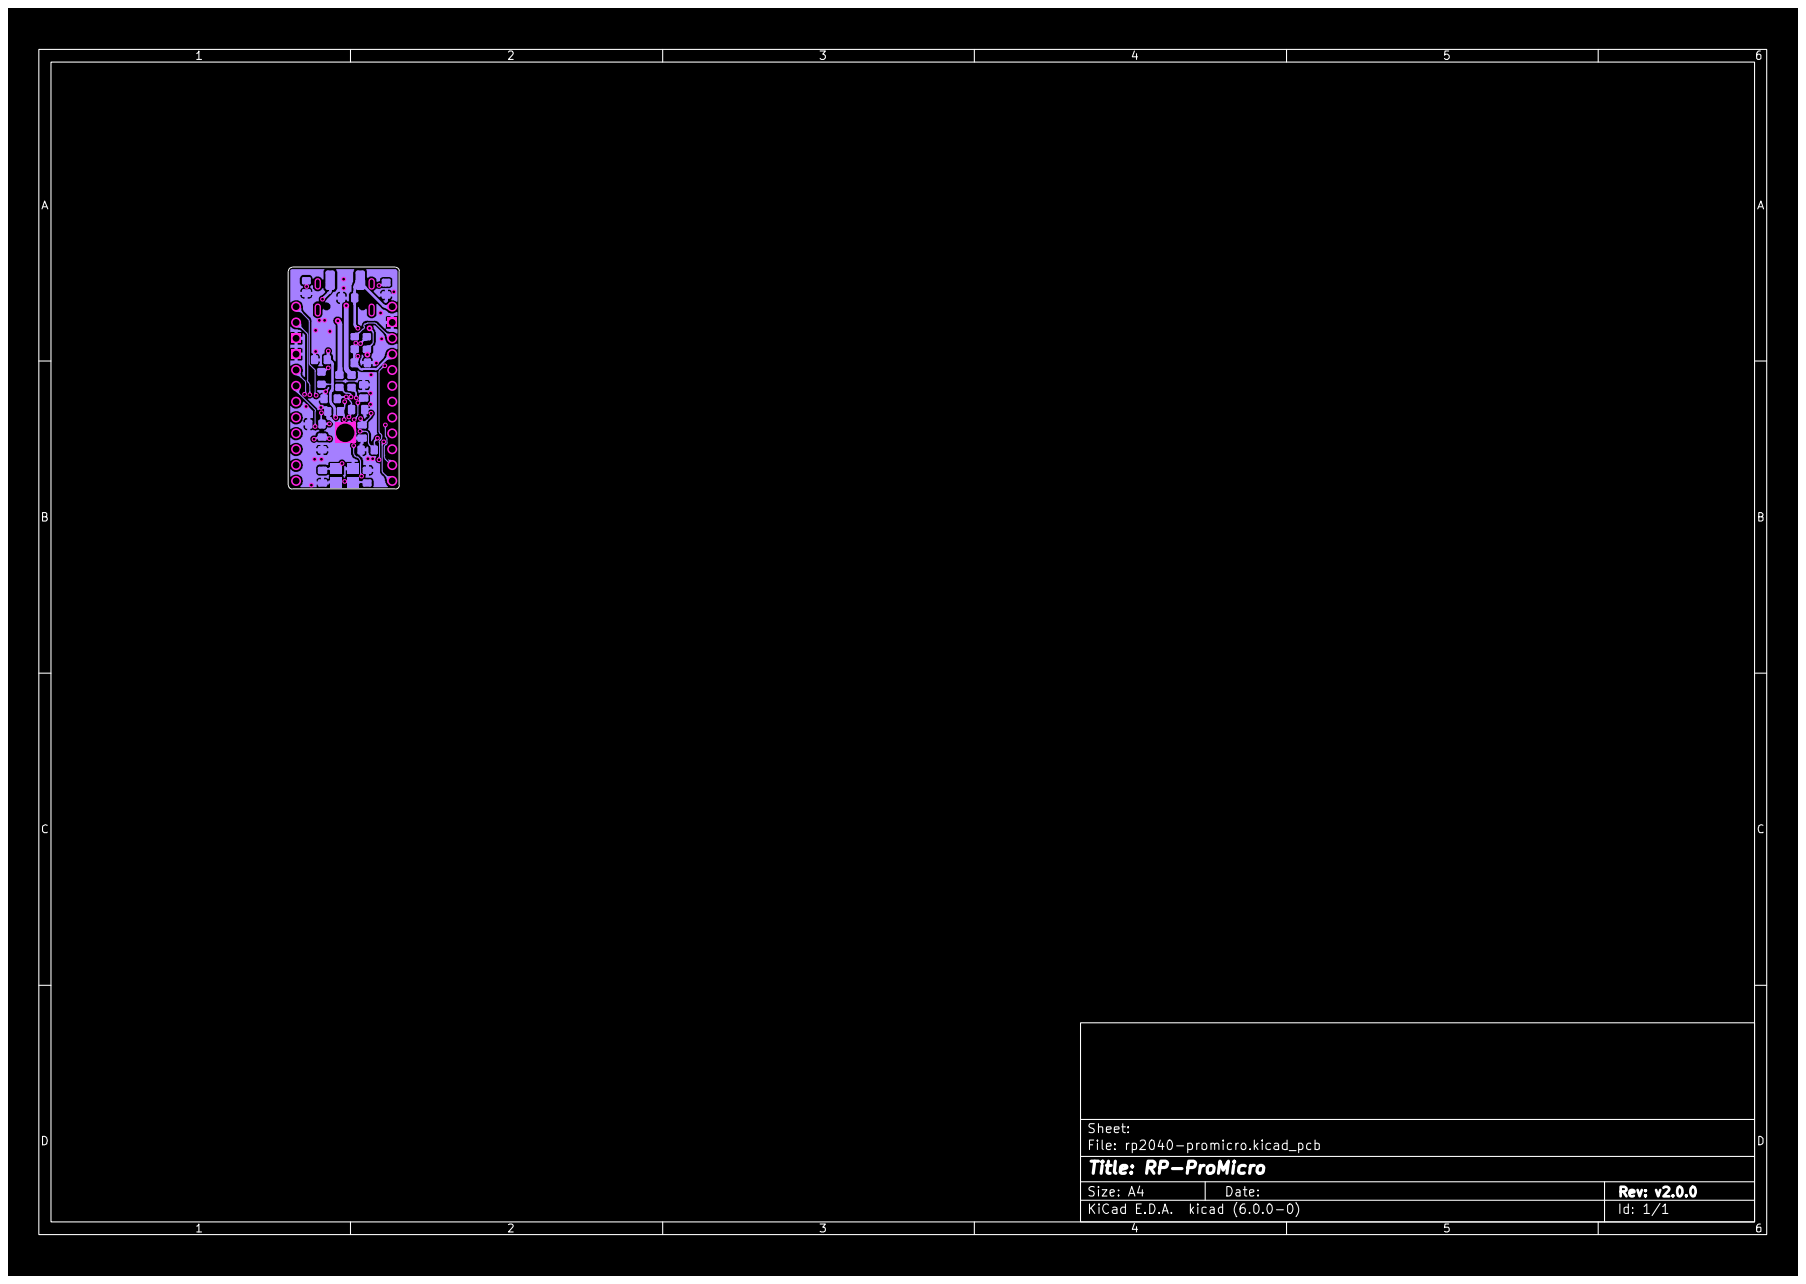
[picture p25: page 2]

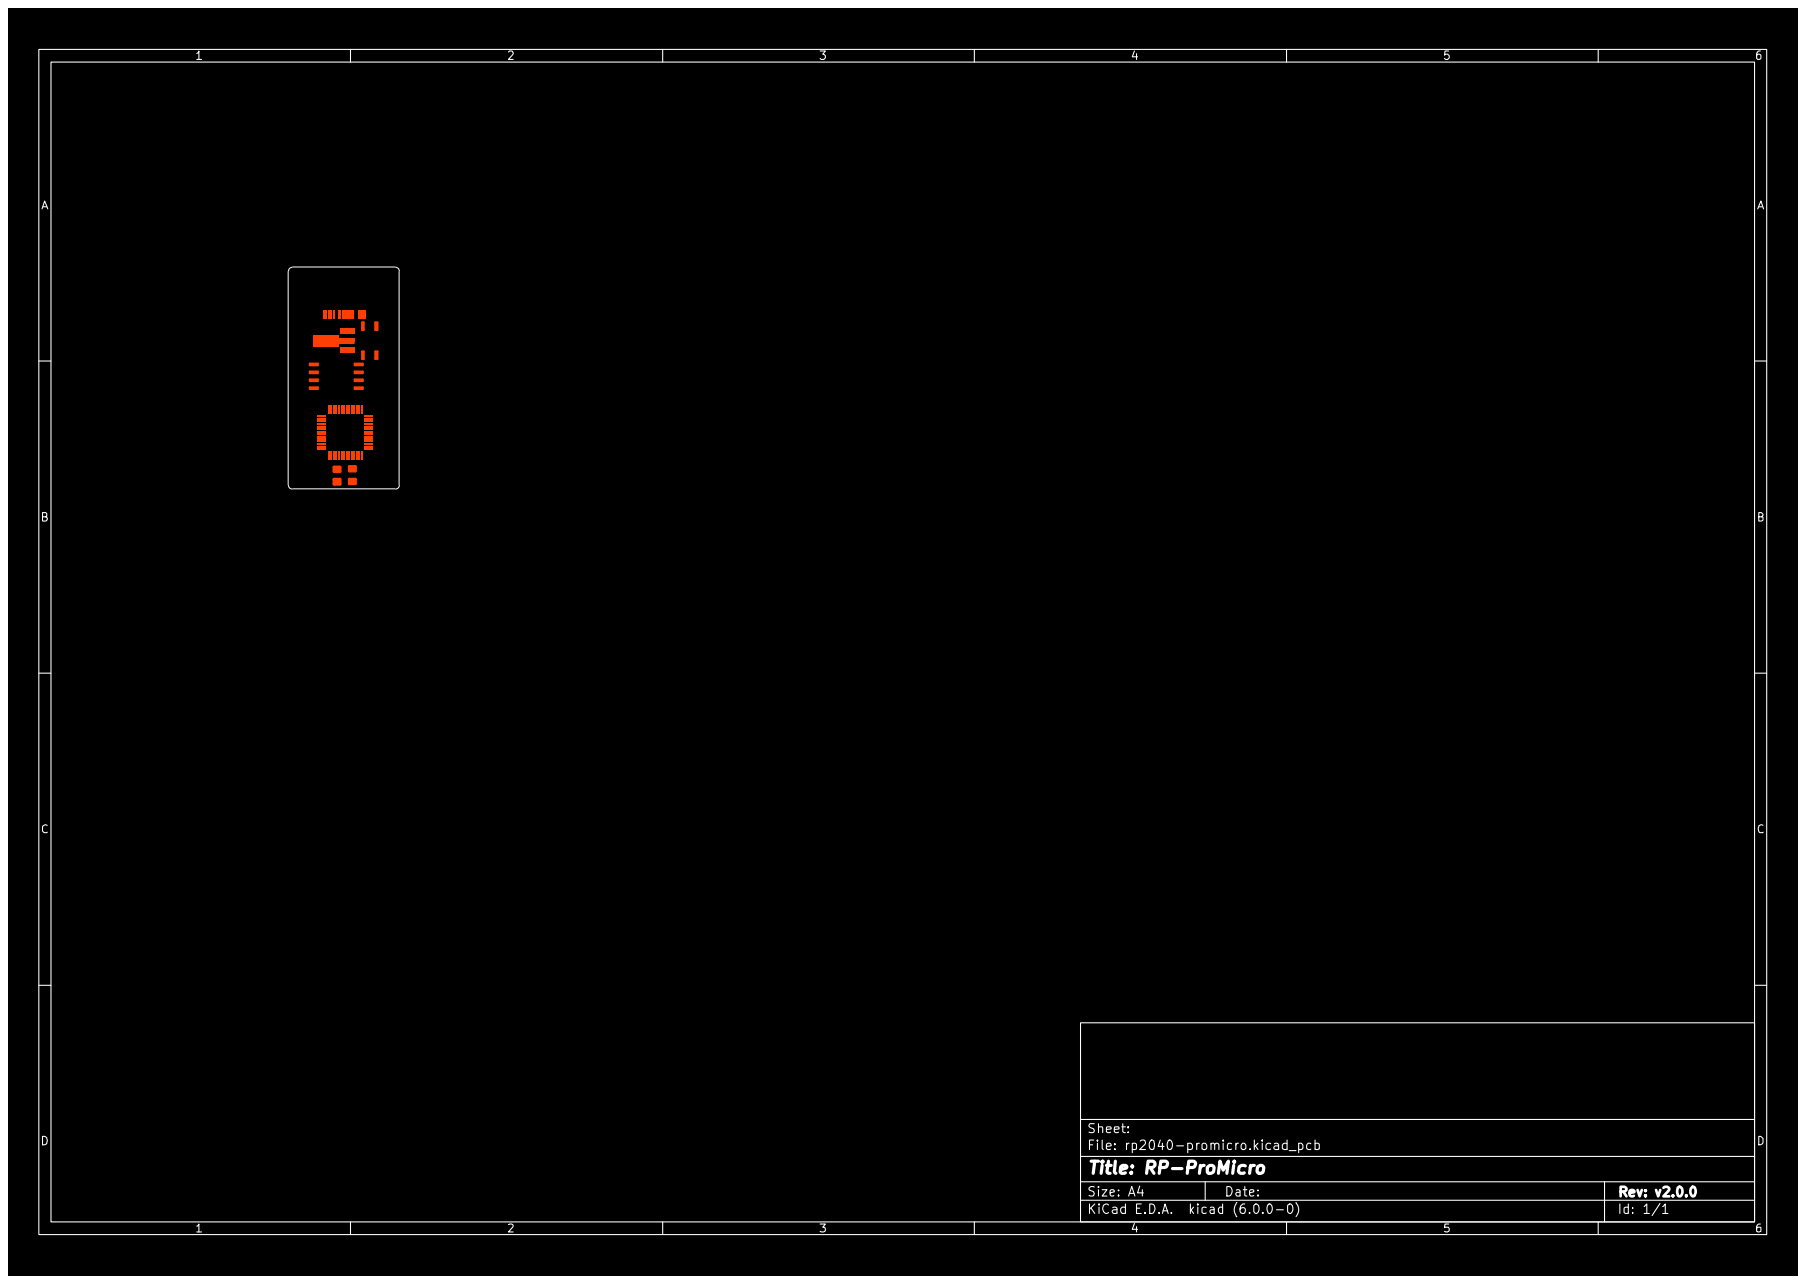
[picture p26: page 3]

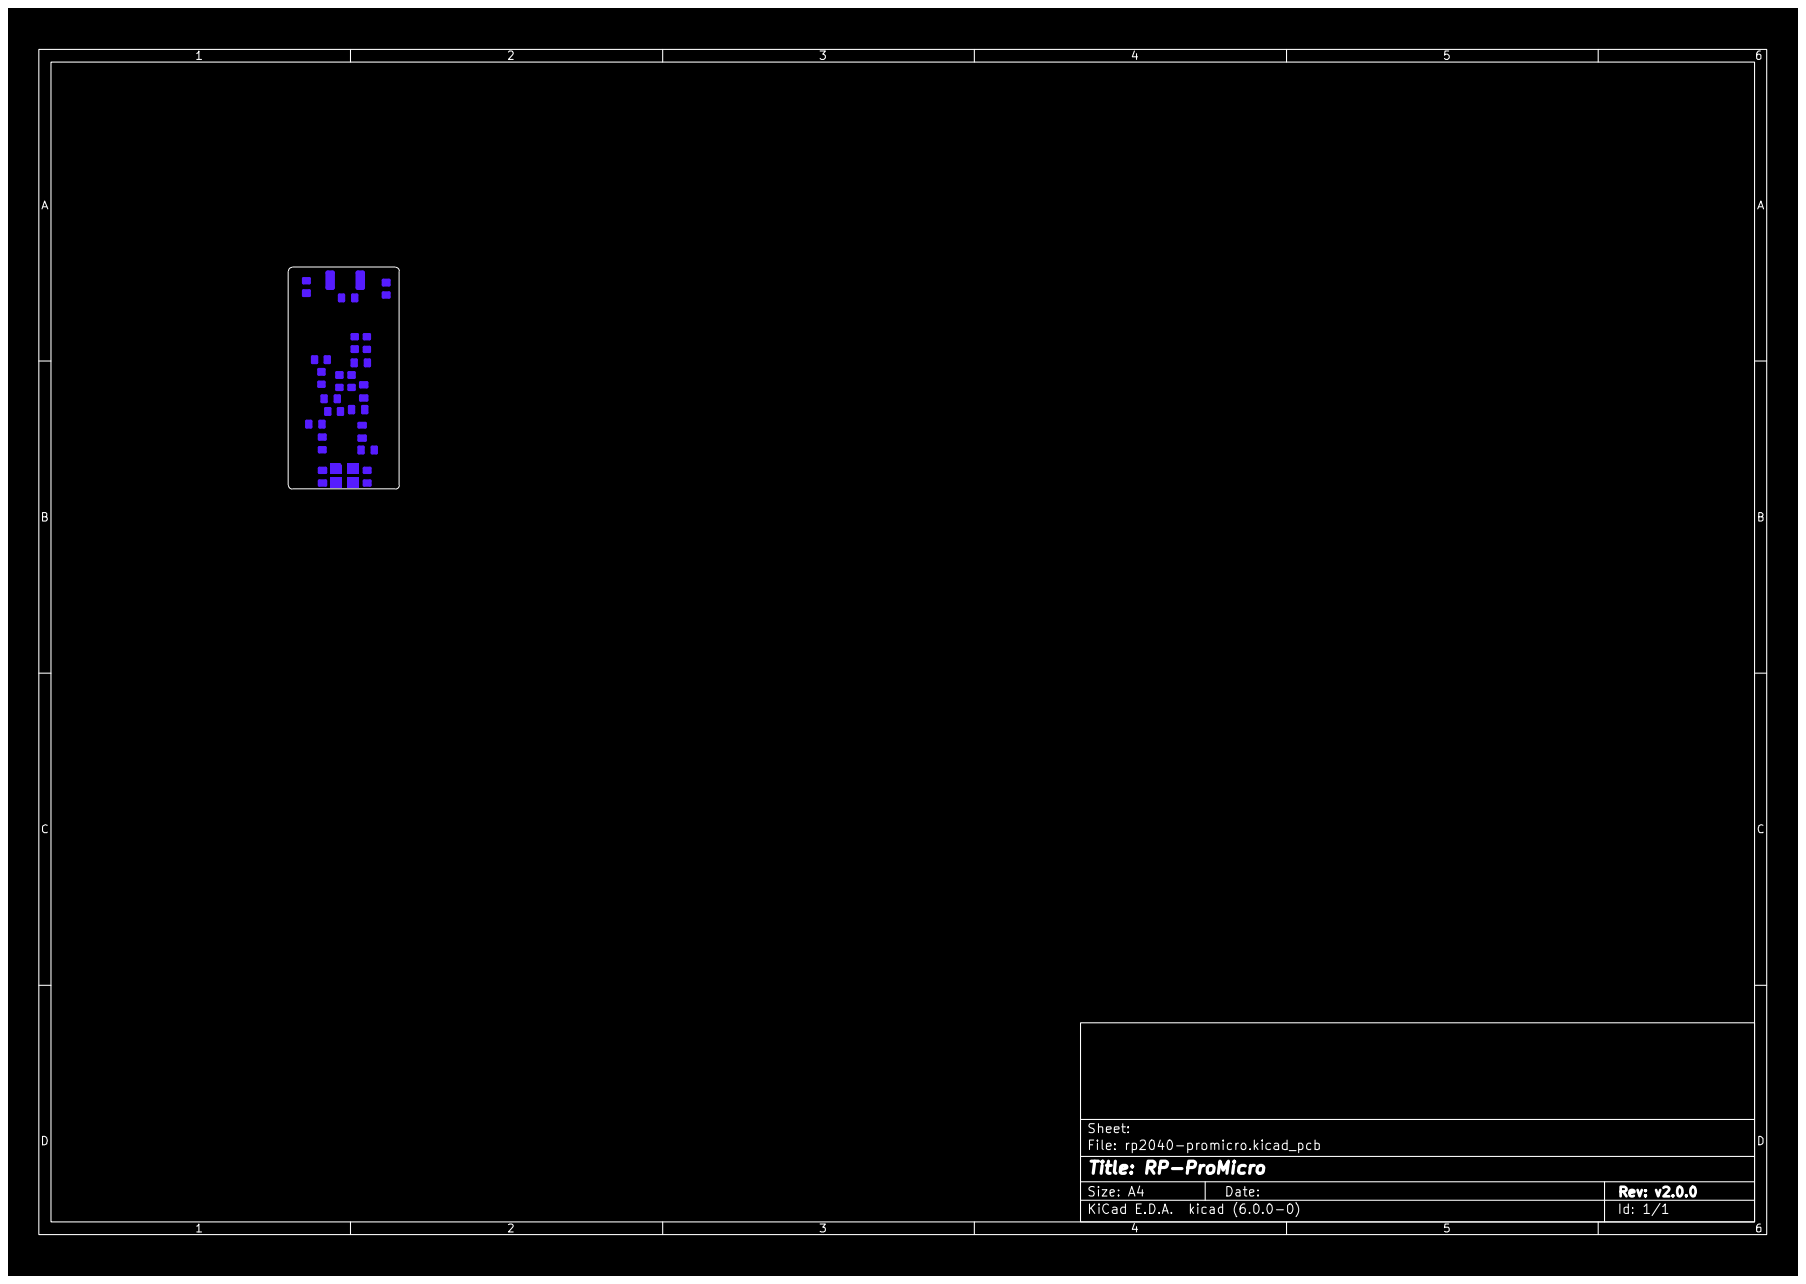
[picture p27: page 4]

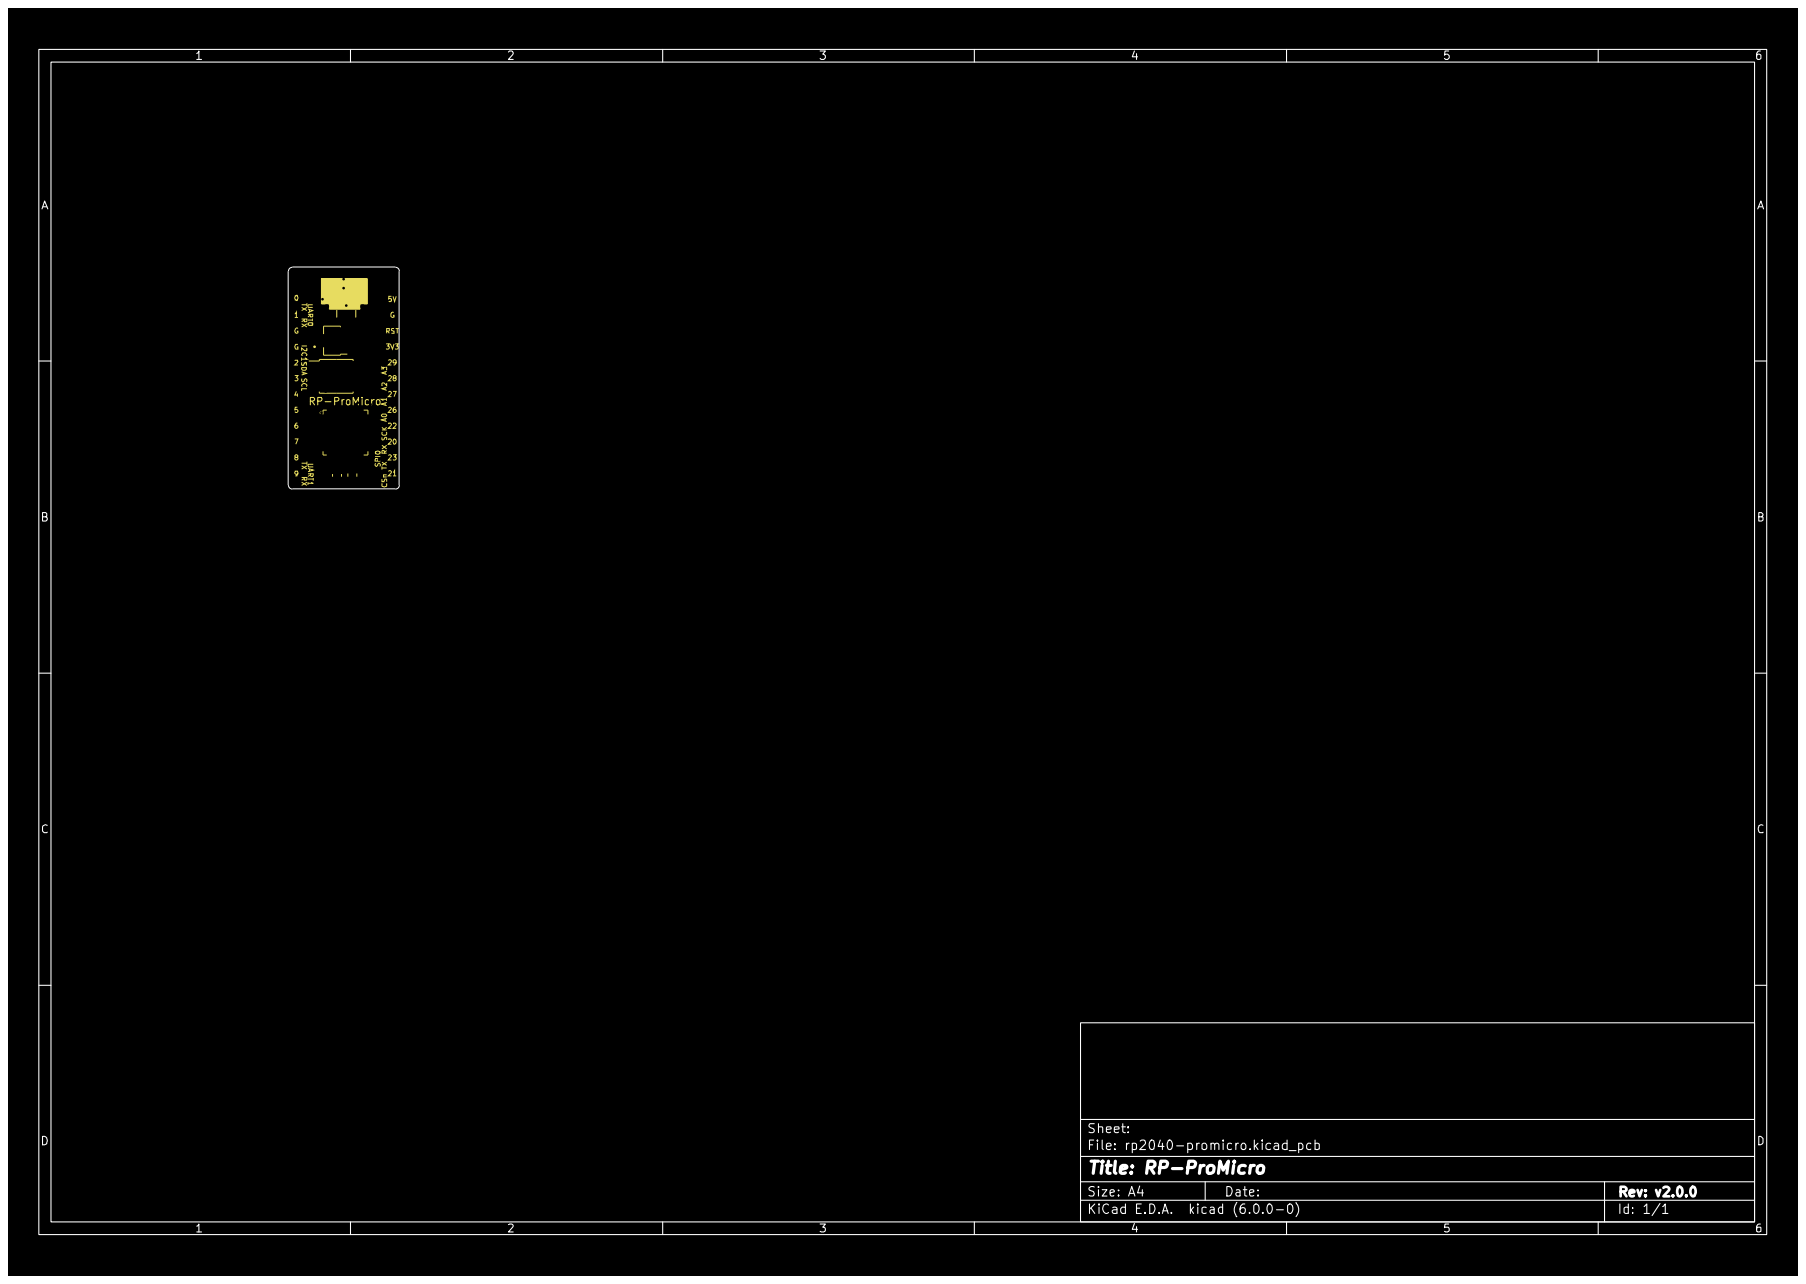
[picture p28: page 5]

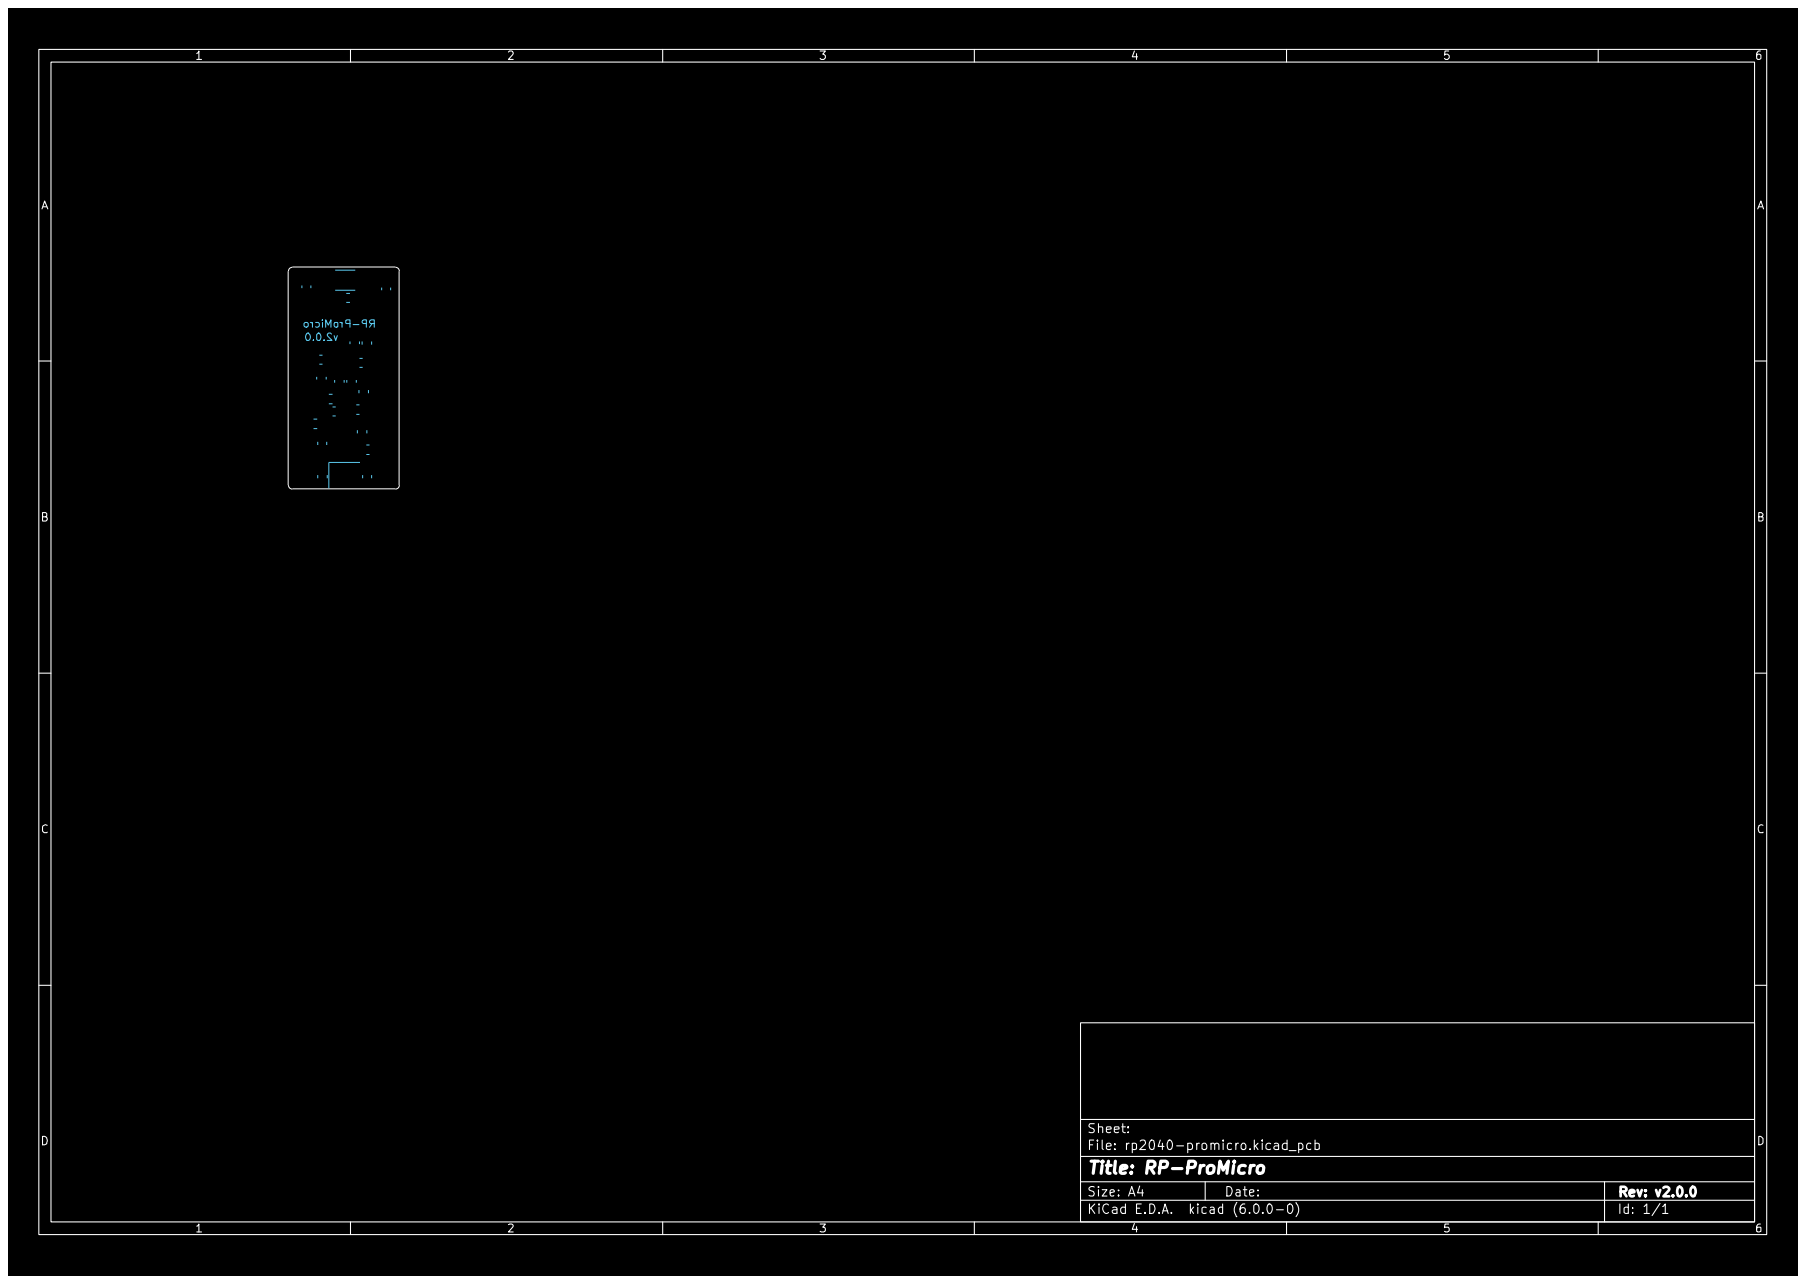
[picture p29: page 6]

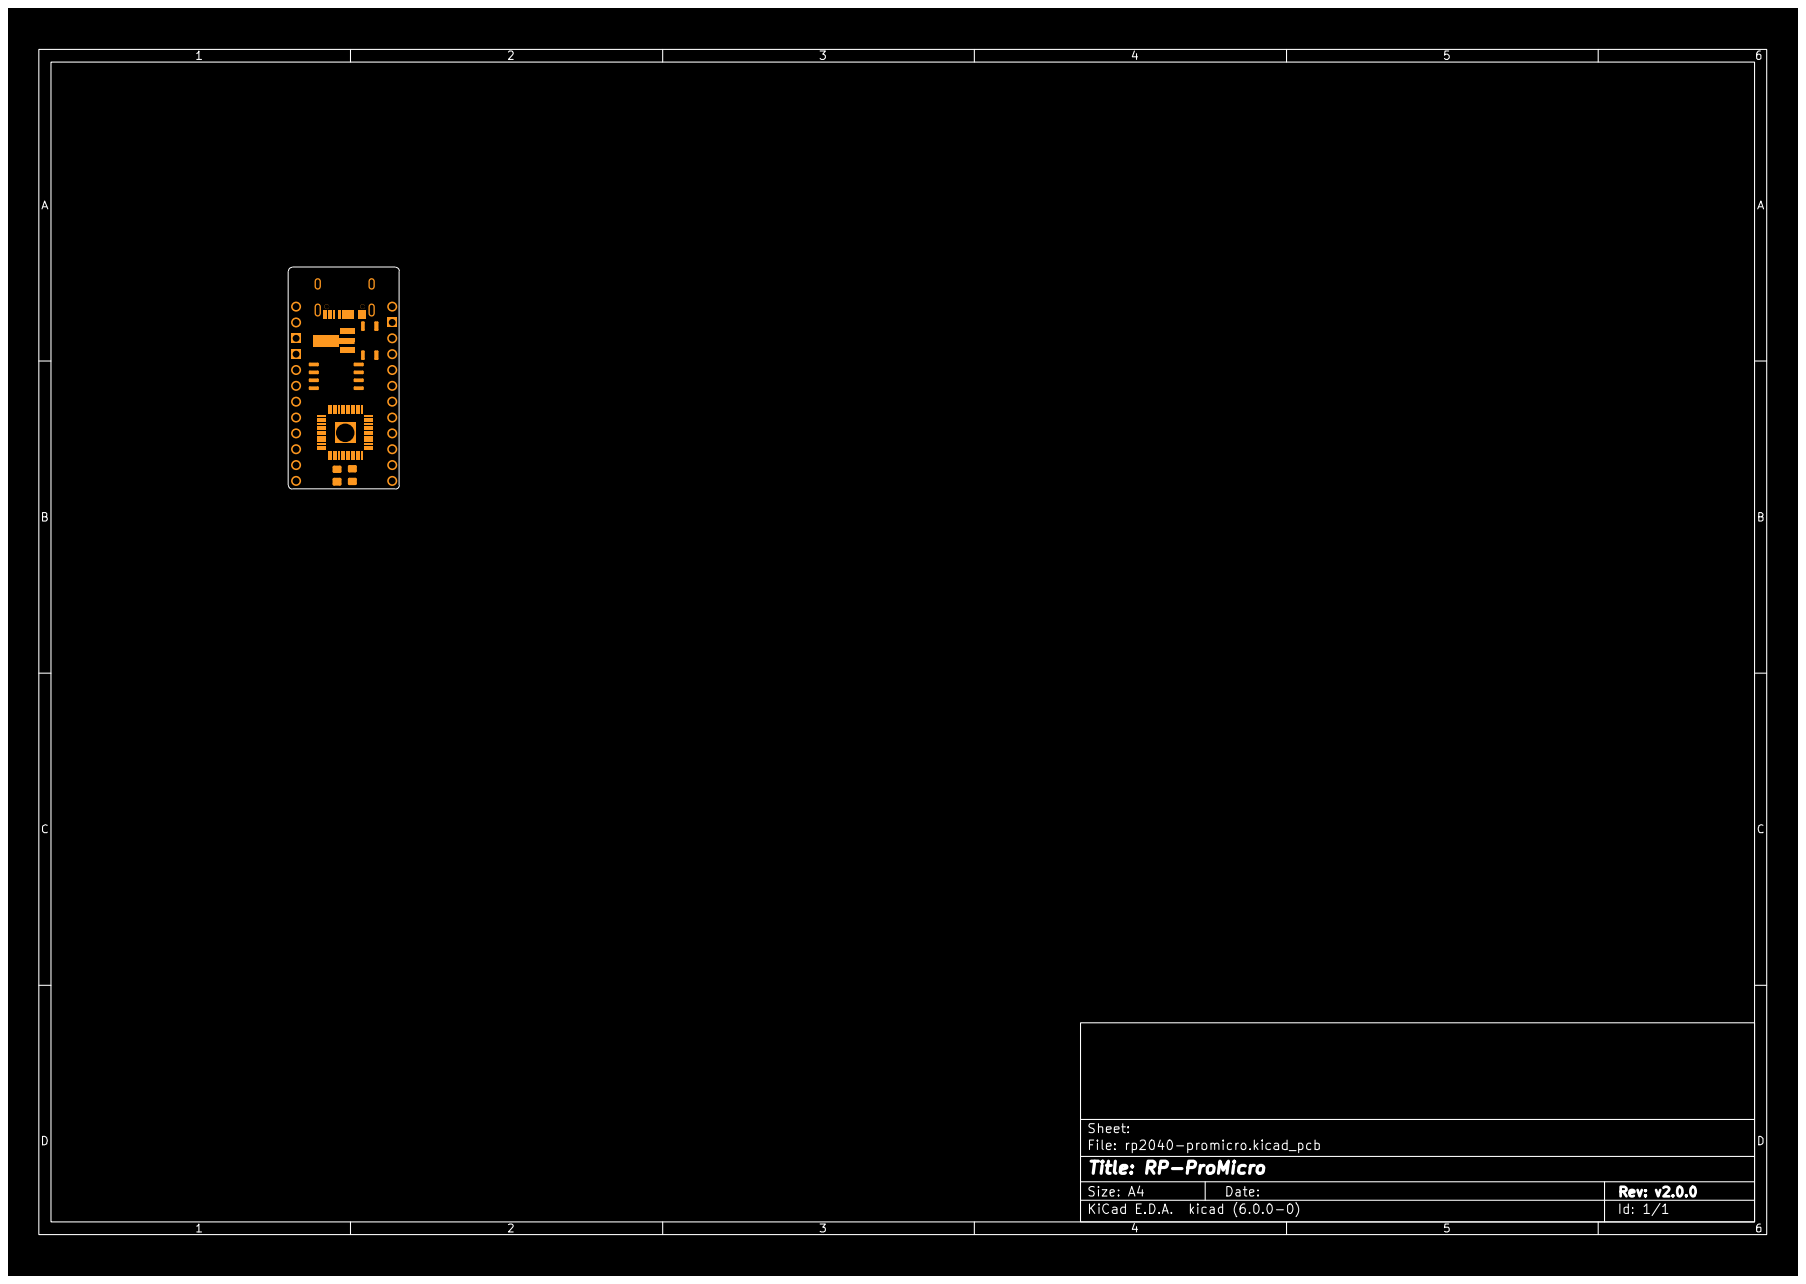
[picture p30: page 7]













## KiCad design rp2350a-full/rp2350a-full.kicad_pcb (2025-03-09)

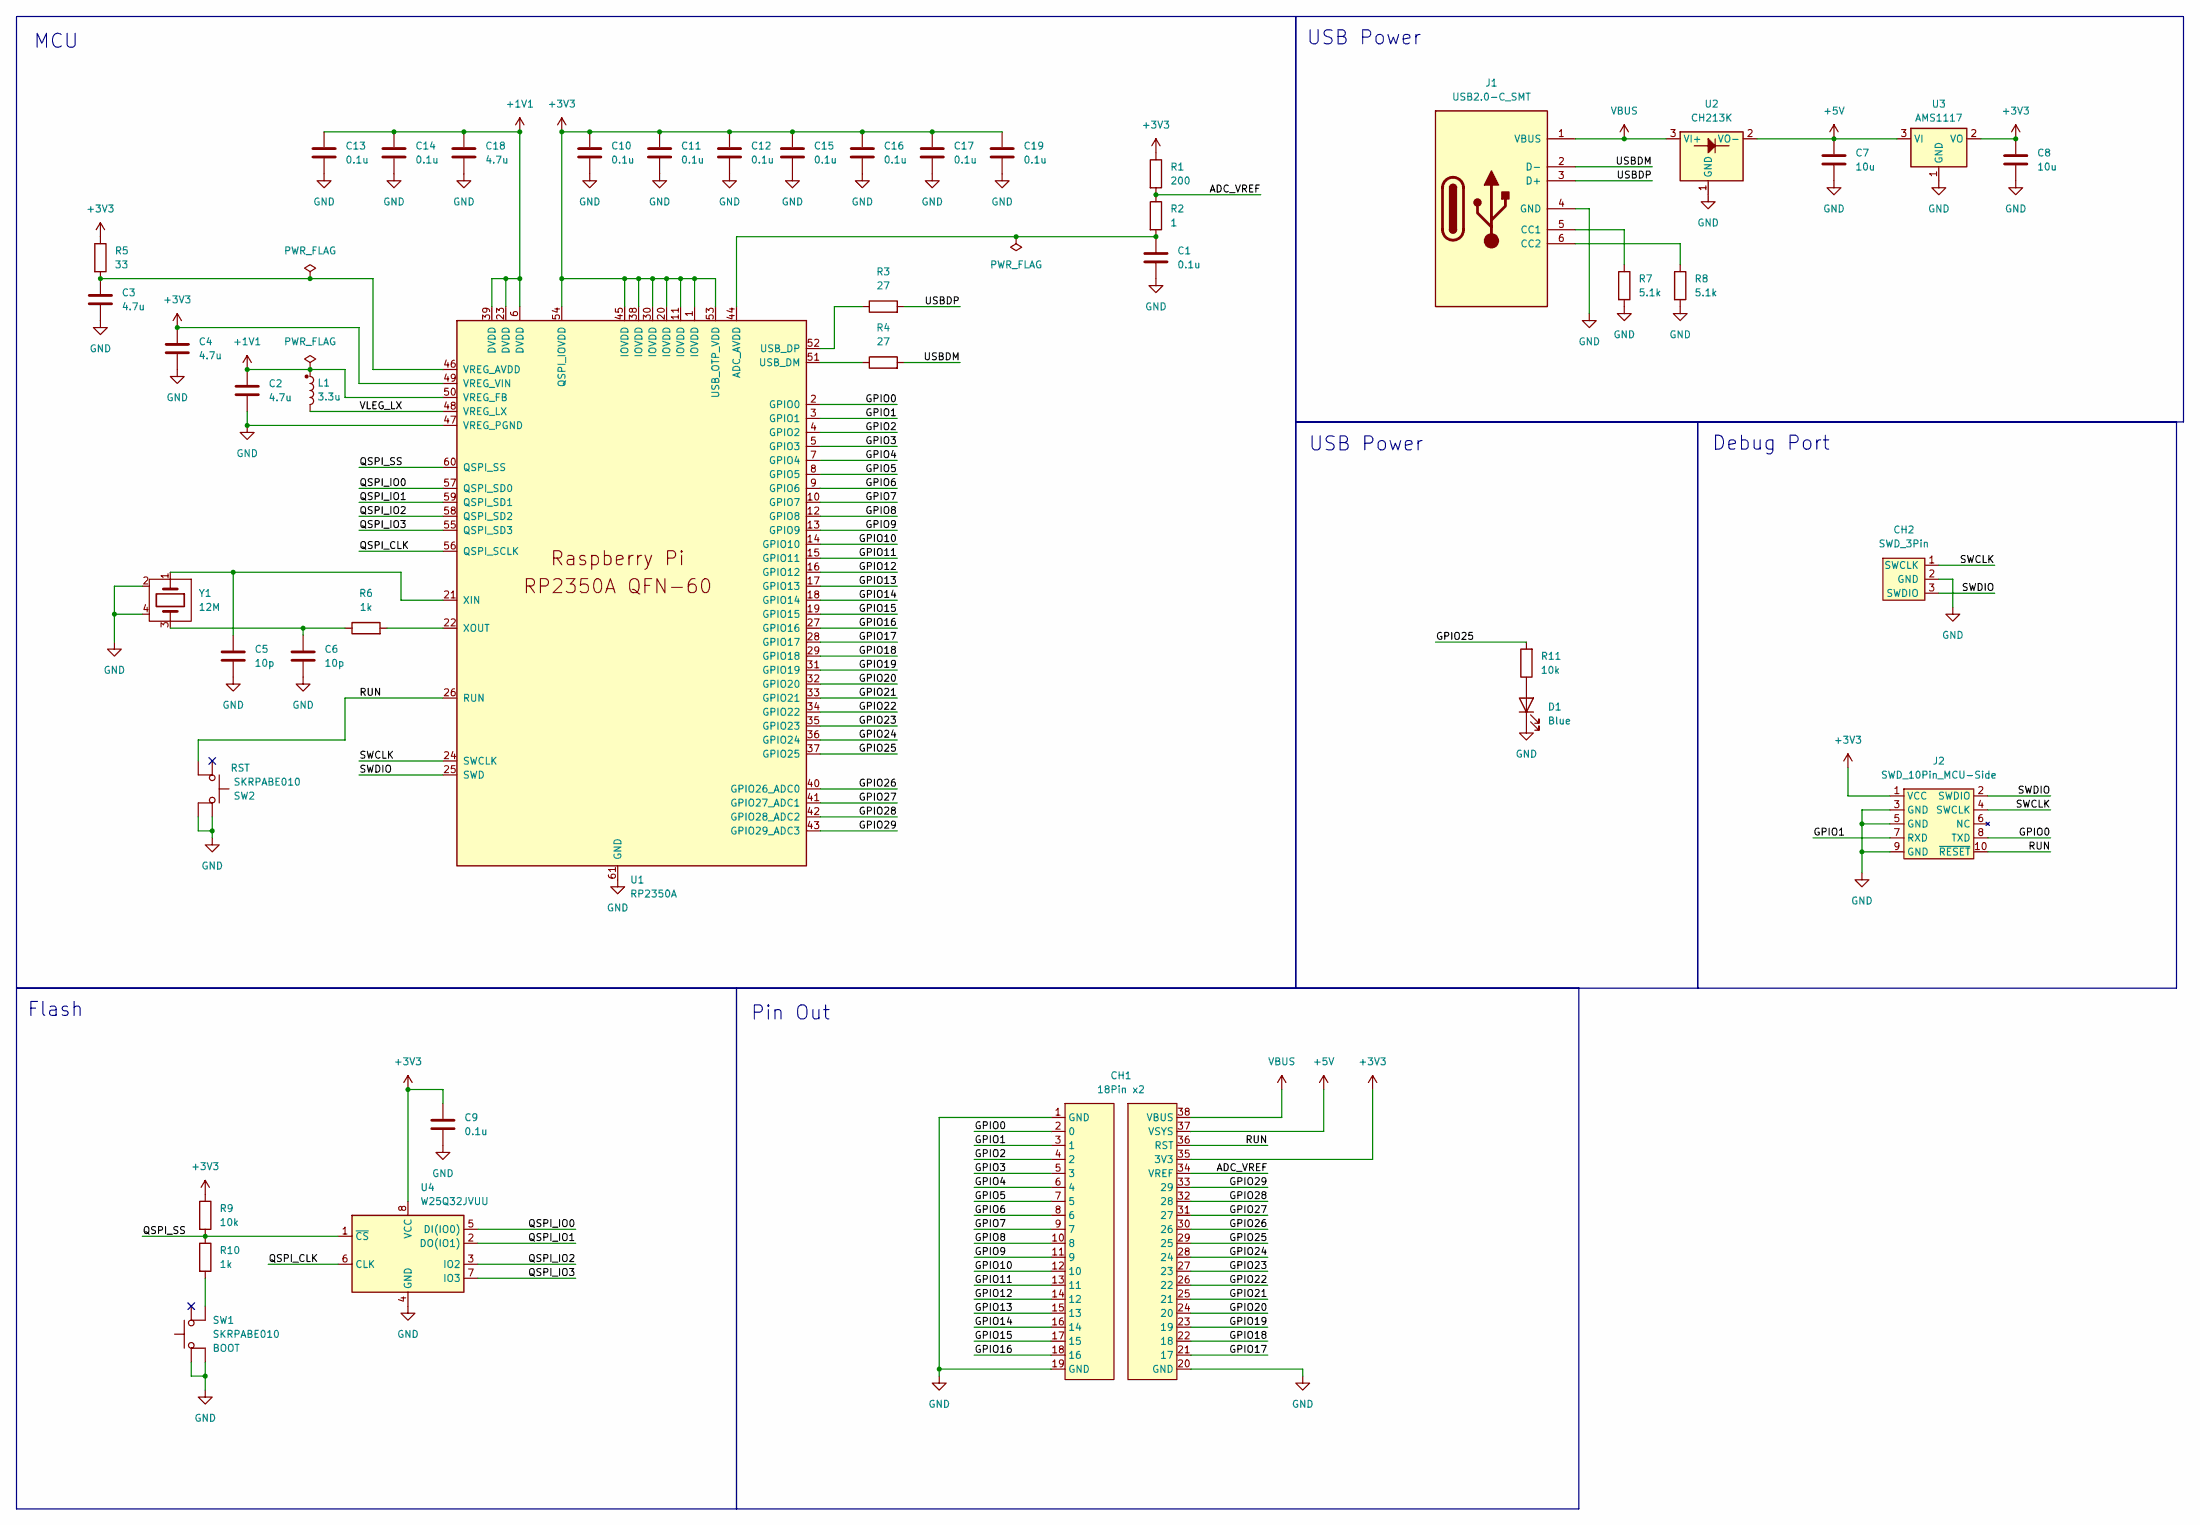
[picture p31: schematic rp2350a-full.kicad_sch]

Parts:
C1, C9, C10, C11, C12, C13, C14, C15, C16, C17, C19: 0.1u; Capacitor_0603_1608
C2, C3, C4, C18: 4.7u; Capacitor_0603_1608
C5, C6: 10p; Capacitor_0603_1608
C7, C8: 10u; Capacitor_0603_1608
CH1: 18Pin x2; PinOut_RP2350-Full
CH2: SWD_3Pin; PinOut_Pin_3_2GND
D1: Blue; LED_0805_2012
J1: USB2.0-C_SMT; Connector_USB-C-Receptacle_SMT_12-Pin_Simple
J2: SWD_10Pin_MCU-Side; Connector_HalfPinHeader_SWD
L1: 3.3u; Inductor_0806_2016
R1: 200; Register_0603_1608
R2: 1; Register_0603_1608
R3, R4: 27; Register_0603_1608
R5: 33; Register_0603_1608
R6, R10: 1k; Register_0603_1608
R7, R8: 5.1k; Register_0603_1608
R9, R11: 10k; Register_0603_1608
SW1, SW2: SKRPABE010; Switch_SKRPABE010_Pin-4
U1: RP2350A; Package_QFN-60-1EP_7x7mm_P0.4mm_EP3.4x3.4mm_hand
U2: CH213K; Package_SOT-23
U3: AMS1117; Package_SOT-89-3
U4: W25Q32JVUU; Package_USON-8_3x4mm_P0.8
Y1: 12M; Crystal_SMD_3225-4Pin_3.2x2.5mm_HandSoldering

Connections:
+1V1: C2.1, C13.1, C14.1, C18.1, L1.1, U1.6 (DVDD), U1.23 (DVDD), U1.39 (DVDD), U1.50 (VREG_FB)
+3V3: C4.1, C8.1, C9.1, C10.1, C11.1, C12.1, C15.1, C16.1, C17.1, C19.1, CH1.35 (3V3), J2.1 (VCC), R1.1, R5.1, R9.1, U1.1 (IOVDD), U1.11 (IOVDD), U1.20 (IOVDD), U1.30 (IOVDD), U1.38 (IOVDD), U1.45 (IOVDD), U1.49 (VREG_VIN), U1.53 (USB_OTP_VDD), U1.54 (QSPI_IOVDD), U3.2 (VO), U4.8 (VCC)
+5V: C7.1, CH1.37 (VSYS), U2.2 (VO-), U3.3 (VI)
/ADC_VREF: CH1.34 (VREF), R1.2, R2.1
/GPIO0: CH1.2 (0), J2.8 (TXD), U1.2 (GPIO0)
/GPIO1: CH1.3 (1), J2.7 (RXD), U1.3 (GPIO1)
/GPIO2: CH1.4 (2), U1.4 (GPIO2)
/GPIO3: CH1.5 (3), U1.5 (GPIO3)
/GPIO4: CH1.6 (4), U1.7 (GPIO4)
/GPIO5: CH1.7 (5), U1.8 (GPIO5)
/GPIO6: CH1.8 (6), U1.9 (GPIO6)
/GPIO7: CH1.9 (7), U1.10 (GPIO7)
/GPIO8: CH1.10 (8), U1.12 (GPIO8)
/GPIO9: CH1.11 (9), U1.13 (GPIO9)
/GPIO10: CH1.12 (10), U1.14 (GPIO10)
/GPIO11: CH1.13 (11), U1.15 (GPIO11)
/GPIO12: CH1.14 (12), U1.16 (GPIO12)
/GPIO13: CH1.15 (13), U1.17 (GPIO13)
/GPIO14: CH1.16 (14), U1.18 (GPIO14)
/GPIO15: CH1.17 (15), U1.19 (GPIO15)
/GPIO16: CH1.18 (16), U1.27 (GPIO16)
/GPIO17: CH1.21 (17), U1.28 (GPIO17)
/GPIO18: CH1.22 (18), U1.29 (GPIO18)
/GPIO19: CH1.23 (19), U1.31 (GPIO19)
/GPIO20: CH1.24 (20), U1.32 (GPIO20)
/GPIO21: CH1.25 (21), U1.33 (GPIO21)
/GPIO22: CH1.26 (22), U1.34 (GPIO22)
/GPIO23: CH1.27 (23), U1.35 (GPIO23)
/GPIO24: CH1.28 (24), U1.36 (GPIO24)
/GPIO25: CH1.29 (25), R11.2, U1.37 (GPIO25)
/GPIO26: CH1.30 (26), U1.40 (GPIO26_ADC0)
/GPIO27: CH1.31 (27), U1.41 (GPIO27_ADC1)
/GPIO28: CH1.32 (28), U1.42 (GPIO28_ADC2)
/GPIO29: CH1.33 (29), U1.43 (GPIO29_ADC3)
/QSPI_CLK: U1.56 (QSPI_SCLK), U4.6 (CLK)
/QSPI_IO0: U1.57 (QSPI_SD0), U4.5 (DI(IO0))
/QSPI_IO1: U1.59 (QSPI_SD1), U4.2 (DO(IO1))
/QSPI_IO2: U1.58 (QSPI_SD2), U4.3 (IO2)
/QSPI_IO3: U1.55 (QSPI_SD3), U4.7 (IO3)
/QSPI_SS: R9.2, R10.1, U1.60 (QSPI_SS), U4.1 (~CS)
/RUN: CH1.36 (RST), J2.10 (~RESET), SW2.4, U1.26 (RUN)
/SWCLK: CH2.1 (SWCLK), J2.4 (SWCLK), U1.24 (SWCLK)
/SWDIO: CH2.3 (SWDIO), J2.2 (SWDIO), U1.25 (SWD)
/USBDM: J1.2 (D-), R4.2
/USBDP: J1.3 (D+), R3.2
/VLEG_LX: L1.2, U1.48 (VREG_LX)
GND: C1.2, C2.2, C3.2, C4.2, C5.2, C6.2, C7.2, C8.2, C9.2, C10.2, C11.2, C12.2, C13.2, C14.2, C15.2, C16.2, C17.2, C18.2, C19.2, CH1.1 (GND), CH1.19 (GND), CH1.20 (GND), CH2.2 (GND), D1.1 (K), J1.4 (GND), J2.3 (GND), J2.5 (GND), J2.9 (GND), R7.2, R8.2, SW1.1, SW1.3, SW2.1, SW2.3, U1.47 (VREG_PGND), U1.61 (GND), U2.1 (GND), U3.1 (GND), U4.4 (GND), Y1.2, Y1.4
unnamed: C6.1, R6.1, Y1.3
unnamed: D1.2 (A), R11.1
unnamed: J1.5 (CC1), R7.1
unnamed: J1.6 (CC2), R8.1
unnamed: R10.2, SW1.4
unnamed: C1.1, R2.2, U1.44 (ADC_AVDD)
unnamed: R4.1, U1.51 (USB_DM)
unnamed: R3.1, U1.52 (USB_DP)
unnamed: C3.1, R5.2, U1.46 (VREG_AVDD)
unnamed: C5.1, U1.21 (XIN), Y1.1
unnamed: R6.2, U1.22 (XOUT)
VBUS: CH1.38 (VBUS), J1.1 (VBUS), U2.3 (VI+)

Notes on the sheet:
Flash
Pin Out
USB Power
Debug Port
MCU

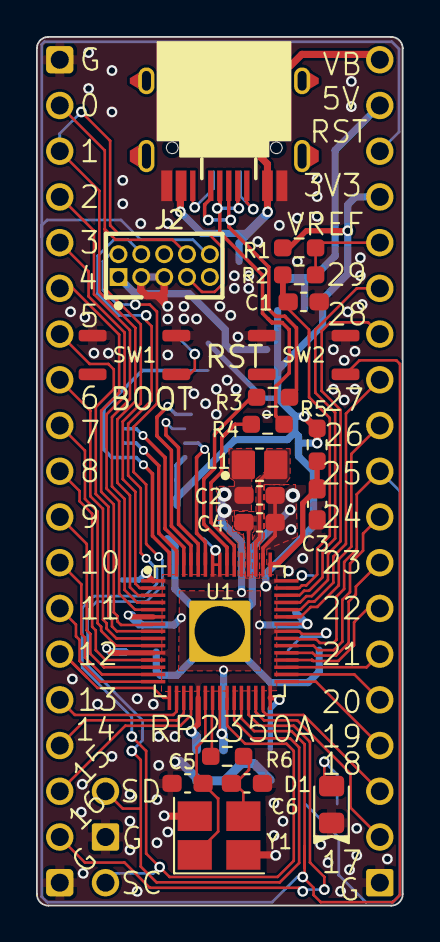
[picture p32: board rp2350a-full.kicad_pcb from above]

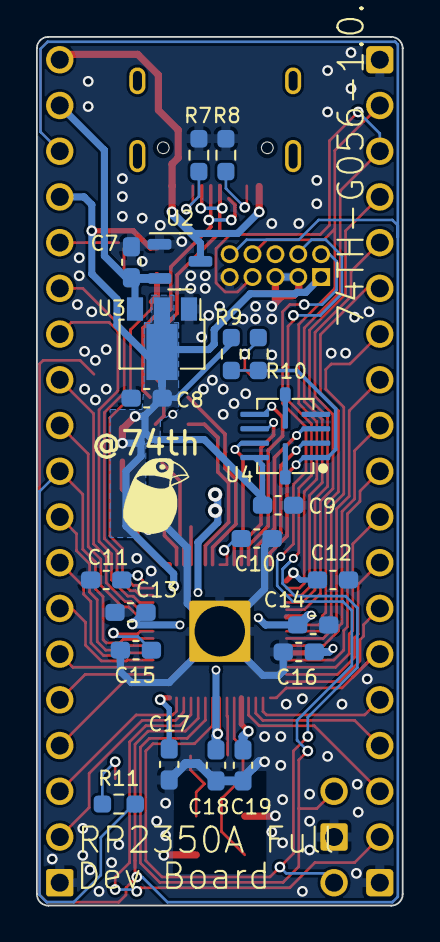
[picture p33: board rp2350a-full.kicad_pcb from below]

Board: 2 copper layers, 20.3 x 48.3 mm, 45 parts (23 on the bottom side), 59 nets.

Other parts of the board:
MISC-ACCOUNTTEXT: Logo_74th_text
MISC-ICON: LOGO; Logo_74th_5mm

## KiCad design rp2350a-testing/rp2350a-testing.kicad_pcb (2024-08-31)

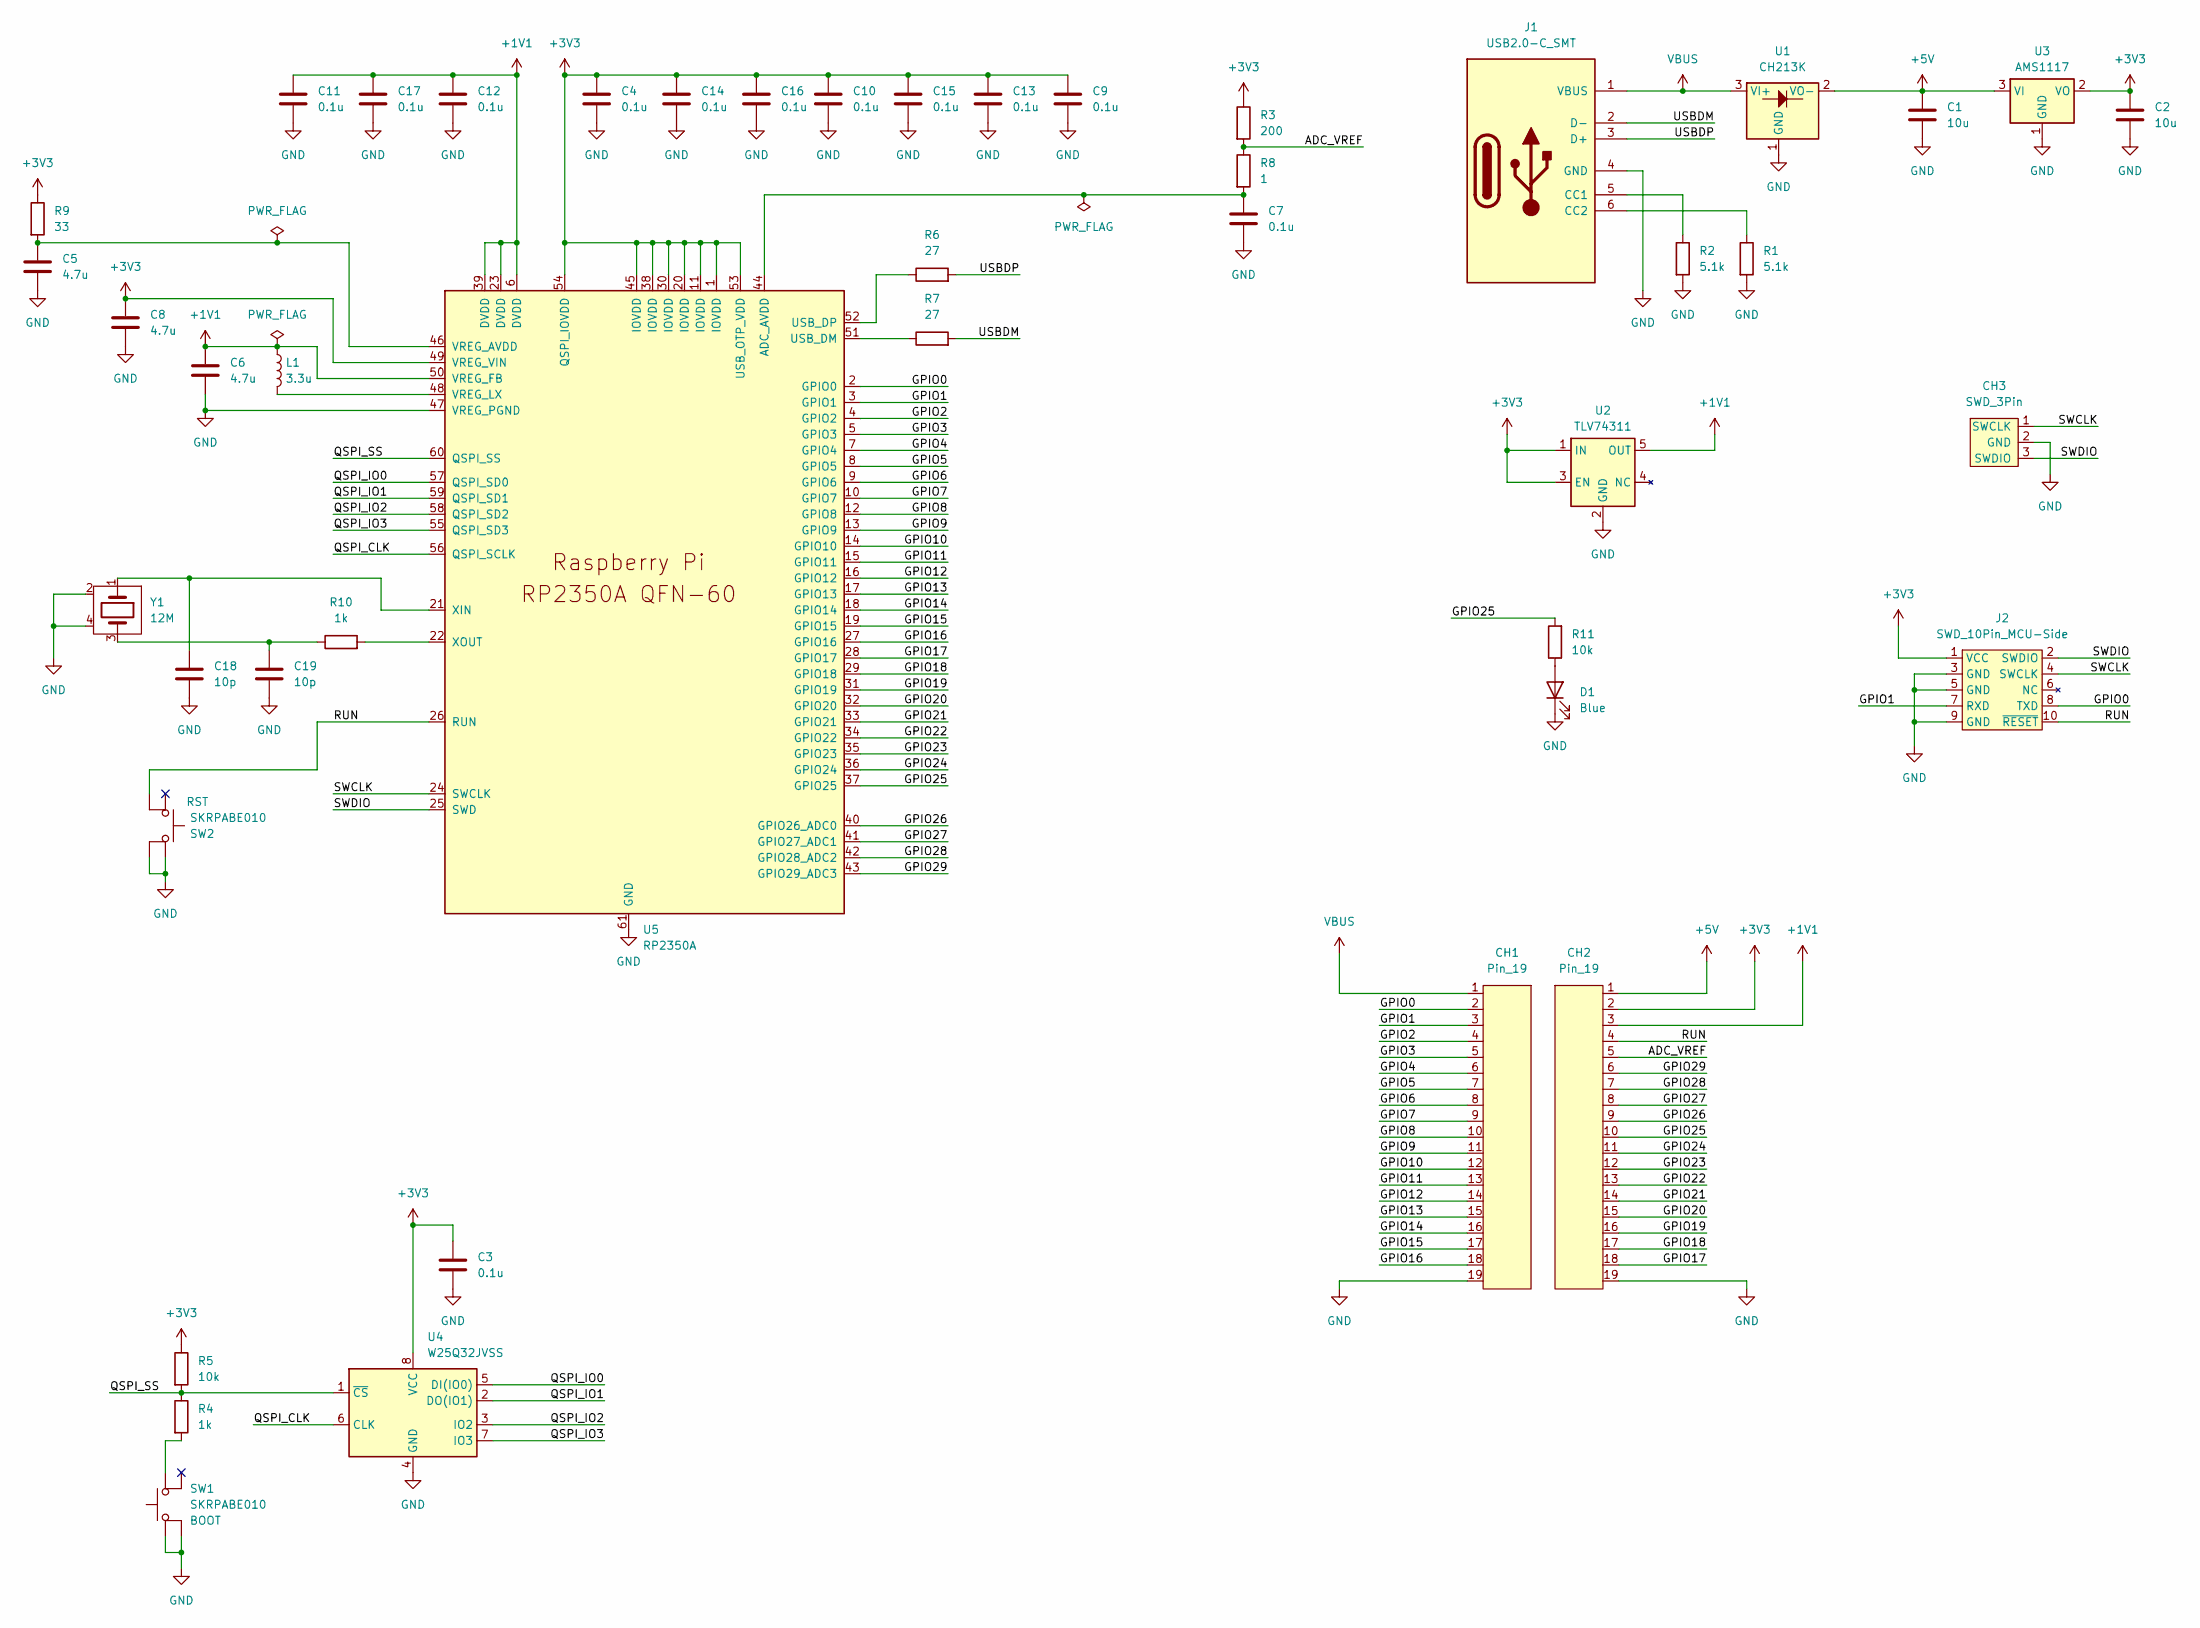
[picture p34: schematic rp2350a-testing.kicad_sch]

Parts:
C1, C2: 10u; Capacitor_0603_1608
C3, C4, C9, C10, C11, C12, C13, C14, C15, C16, C17: 0.1u; Capacitor_0402_1005
C5, C6, C8: 4.7u; Capacitor_0402_1005_m
C7: 0.1u; Capacitor_0603_1608
C18, C19: 10p; Capacitor_0402_1005
CH1, CH2: Pin_19; PinOut_Pin_19
CH3: SWD_3Pin; PinOut_Pin_3_2GND
D1: Blue; LED_0805_2012
J1: USB2.0-C_SMT; Connector_USB-C-Receptacle_SMT_12-Pin_Simple
J2: SWD_10Pin_MCU-Side; Connector_HalfPinHeader_SWD
L1: 3.3u; Inductor_4.1x4.5mm_testing
R1, R2: 5.1k; Register_0603_1608
R3: 200; Register_0603_1608
R4: 1k; Register_0603_1608
R5, R11: 10k; Register_0603_1608
R6, R7: 27; Register_0603_1608
R8: 1; Register_0603_1608
R9: 33; Register_0603_1608
R10: 1k; Register_0402_1005
SW1, SW2: SKRPABE010; Switch_SKRPABE010_Pin-4
U1: CH213K; Package_SOT-23
U2: TLV74311; Package_SOT-23-5
U3: AMS1117; Package_SOT-89-3
U4: W25Q32JVSS; Package_USON-8_3x4mm_P0.8
U5: RP2350A; Package_QFN-60-1EP_7x7mm_P0.4mm_EP3.4x3.4mm_hand
Y1: 12M; Crystal_SMD_3225-4Pin_3.2x2.5mm_HandSoldering

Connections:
+1V1: C6.1, C11.1, C12.1, C17.1, CH2.3, L1.1, U2.5 (OUT), U5.6 (DVDD), U5.23 (DVDD), U5.39 (DVDD), U5.50 (VREG_FB)
+3V3: C2.1, C3.1, C4.1, C8.1, C9.1, C10.1, C13.1, C14.1, C15.1, C16.1, CH2.2, J2.1 (VCC), R3.1, R5.1, R9.1, U2.1 (IN), U2.3 (EN), U3.2 (VO), U4.8 (VCC), U5.1 (IOVDD), U5.11 (IOVDD), U5.20 (IOVDD), U5.30 (IOVDD), U5.38 (IOVDD), U5.45 (IOVDD), U5.49 (VREG_VIN), U5.53 (USB_OTP_VDD), U5.54 (QSPI_IOVDD)
+5V: C1.1, CH2.1, U1.2 (VO-), U3.3 (VI)
/ADC_VREF: CH2.5, R3.2, R8.1
/GPIO0: CH1.2, J2.8 (TXD), U5.2 (GPIO0)
/GPIO1: CH1.3, J2.7 (RXD), U5.3 (GPIO1)
/GPIO2: CH1.4, U5.4 (GPIO2)
/GPIO3: CH1.5, U5.5 (GPIO3)
/GPIO4: CH1.6, U5.7 (GPIO4)
/GPIO5: CH1.7, U5.8 (GPIO5)
/GPIO6: CH1.8, U5.9 (GPIO6)
/GPIO7: CH1.9, U5.10 (GPIO7)
/GPIO8: CH1.10, U5.12 (GPIO8)
/GPIO9: CH1.11, U5.13 (GPIO9)
/GPIO10: CH1.12, U5.14 (GPIO10)
/GPIO11: CH1.13, U5.15 (GPIO11)
/GPIO12: CH1.14, U5.16 (GPIO12)
/GPIO13: CH1.15, U5.17 (GPIO13)
/GPIO14: CH1.16, U5.18 (GPIO14)
/GPIO15: CH1.17, U5.19 (GPIO15)
/GPIO16: CH1.18, U5.27 (GPIO16)
/GPIO17: CH2.18, U5.28 (GPIO17)
/GPIO18: CH2.17, U5.29 (GPIO18)
/GPIO19: CH2.16, U5.31 (GPIO19)
/GPIO20: CH2.15, U5.32 (GPIO20)
/GPIO21: CH2.14, U5.33 (GPIO21)
/GPIO22: CH2.13, U5.34 (GPIO22)
/GPIO23: CH2.12, U5.35 (GPIO23)
/GPIO24: CH2.11, U5.36 (GPIO24)
/GPIO25: CH2.10, R11.2, U5.37 (GPIO25)
/GPIO26: CH2.9, U5.40 (GPIO26_ADC0)
/GPIO27: CH2.8, U5.41 (GPIO27_ADC1)
/GPIO28: CH2.7, U5.42 (GPIO28_ADC2)
/GPIO29: CH2.6, U5.43 (GPIO29_ADC3)
/QSPI_CLK: U4.6 (CLK), U5.56 (QSPI_SCLK)
/QSPI_IO0: U4.5 (DI(IO0)), U5.57 (QSPI_SD0)
/QSPI_IO1: U4.2 (DO(IO1)), U5.59 (QSPI_SD1)
/QSPI_IO2: U4.3 (IO2), U5.58 (QSPI_SD2)
/QSPI_IO3: U4.7 (IO3), U5.55 (QSPI_SD3)
/QSPI_SS: R4.1, R5.2, U4.1 (~CS), U5.60 (QSPI_SS)
/RUN: CH2.4, J2.10 (~RESET), SW2.4, U5.26 (RUN)
/SWCLK: CH3.1 (SWCLK), J2.4 (SWCLK), U5.24 (SWCLK)
/SWDIO: CH3.3 (SWDIO), J2.2 (SWDIO), U5.25 (SWD)
/USBDM: J1.2 (D-), R7.2
/USBDP: J1.3 (D+), R6.2
GND: C1.2, C2.2, C3.2, C4.2, C5.2, C6.2, C7.2, C8.2, C9.2, C10.2, C11.2, C12.2, C13.2, C14.2, C15.2, C16.2, C17.2, C18.2, C19.2, CH1.19, CH2.19, CH3.2 (GND), D1.1 (K), J1.4 (GND), J2.3 (GND), J2.5 (GND), J2.9 (GND), R1.2, R2.2, SW1.1, SW1.3, SW2.1, SW2.3, U1.1 (GND), U2.2 (GND), U3.1 (GND), U4.4 (GND), U5.47 (VREG_PGND), U5.61 (GND), Y1.2, Y1.4
unnamed: C19.1, R10.1, Y1.3
unnamed: D1.2 (A), R11.1
unnamed: J1.5 (CC1), R2.1
unnamed: J1.6 (CC2), R1.1
unnamed: R4.2, SW1.2
unnamed: C7.1, R8.2, U5.44 (ADC_AVDD)
unnamed: R7.1, U5.51 (USB_DM)
unnamed: R6.1, U5.52 (USB_DP)
unnamed: C5.1, R9.2, U5.46 (VREG_AVDD)
unnamed: L1.2, U5.48 (VREG_LX)
unnamed: C18.1, U5.21 (XIN), Y1.1
unnamed: R10.2, U5.22 (XOUT)
VBUS: CH1.1, J1.1 (VBUS), U1.3 (VI+)

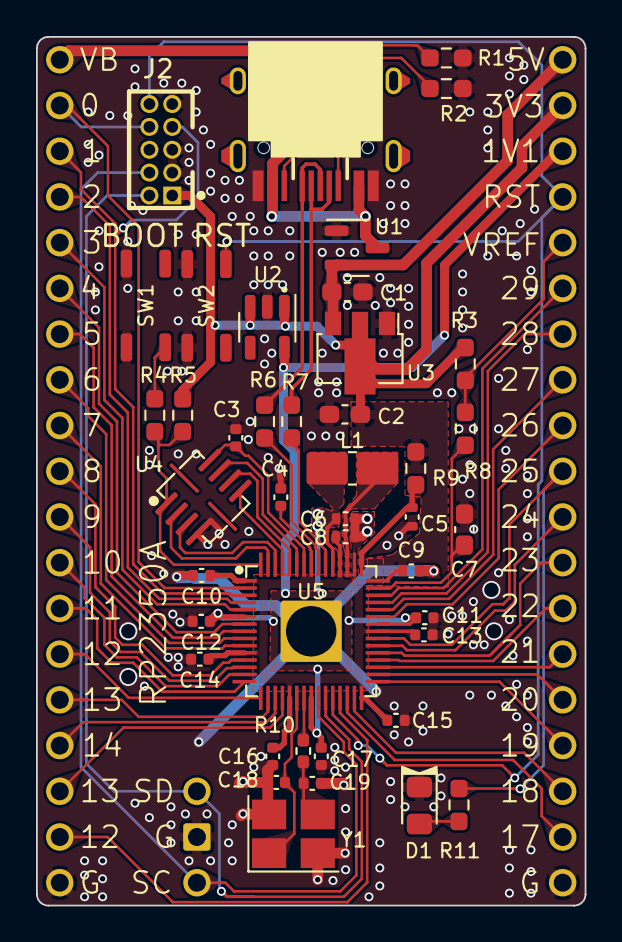
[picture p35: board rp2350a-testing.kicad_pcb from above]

Board: 2 copper layers, 30.5 x 48.3 mm, 46 parts (1 on the bottom side), 59 nets.

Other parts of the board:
MISC-ICON: LOGO; Logo_74th_7.5mm

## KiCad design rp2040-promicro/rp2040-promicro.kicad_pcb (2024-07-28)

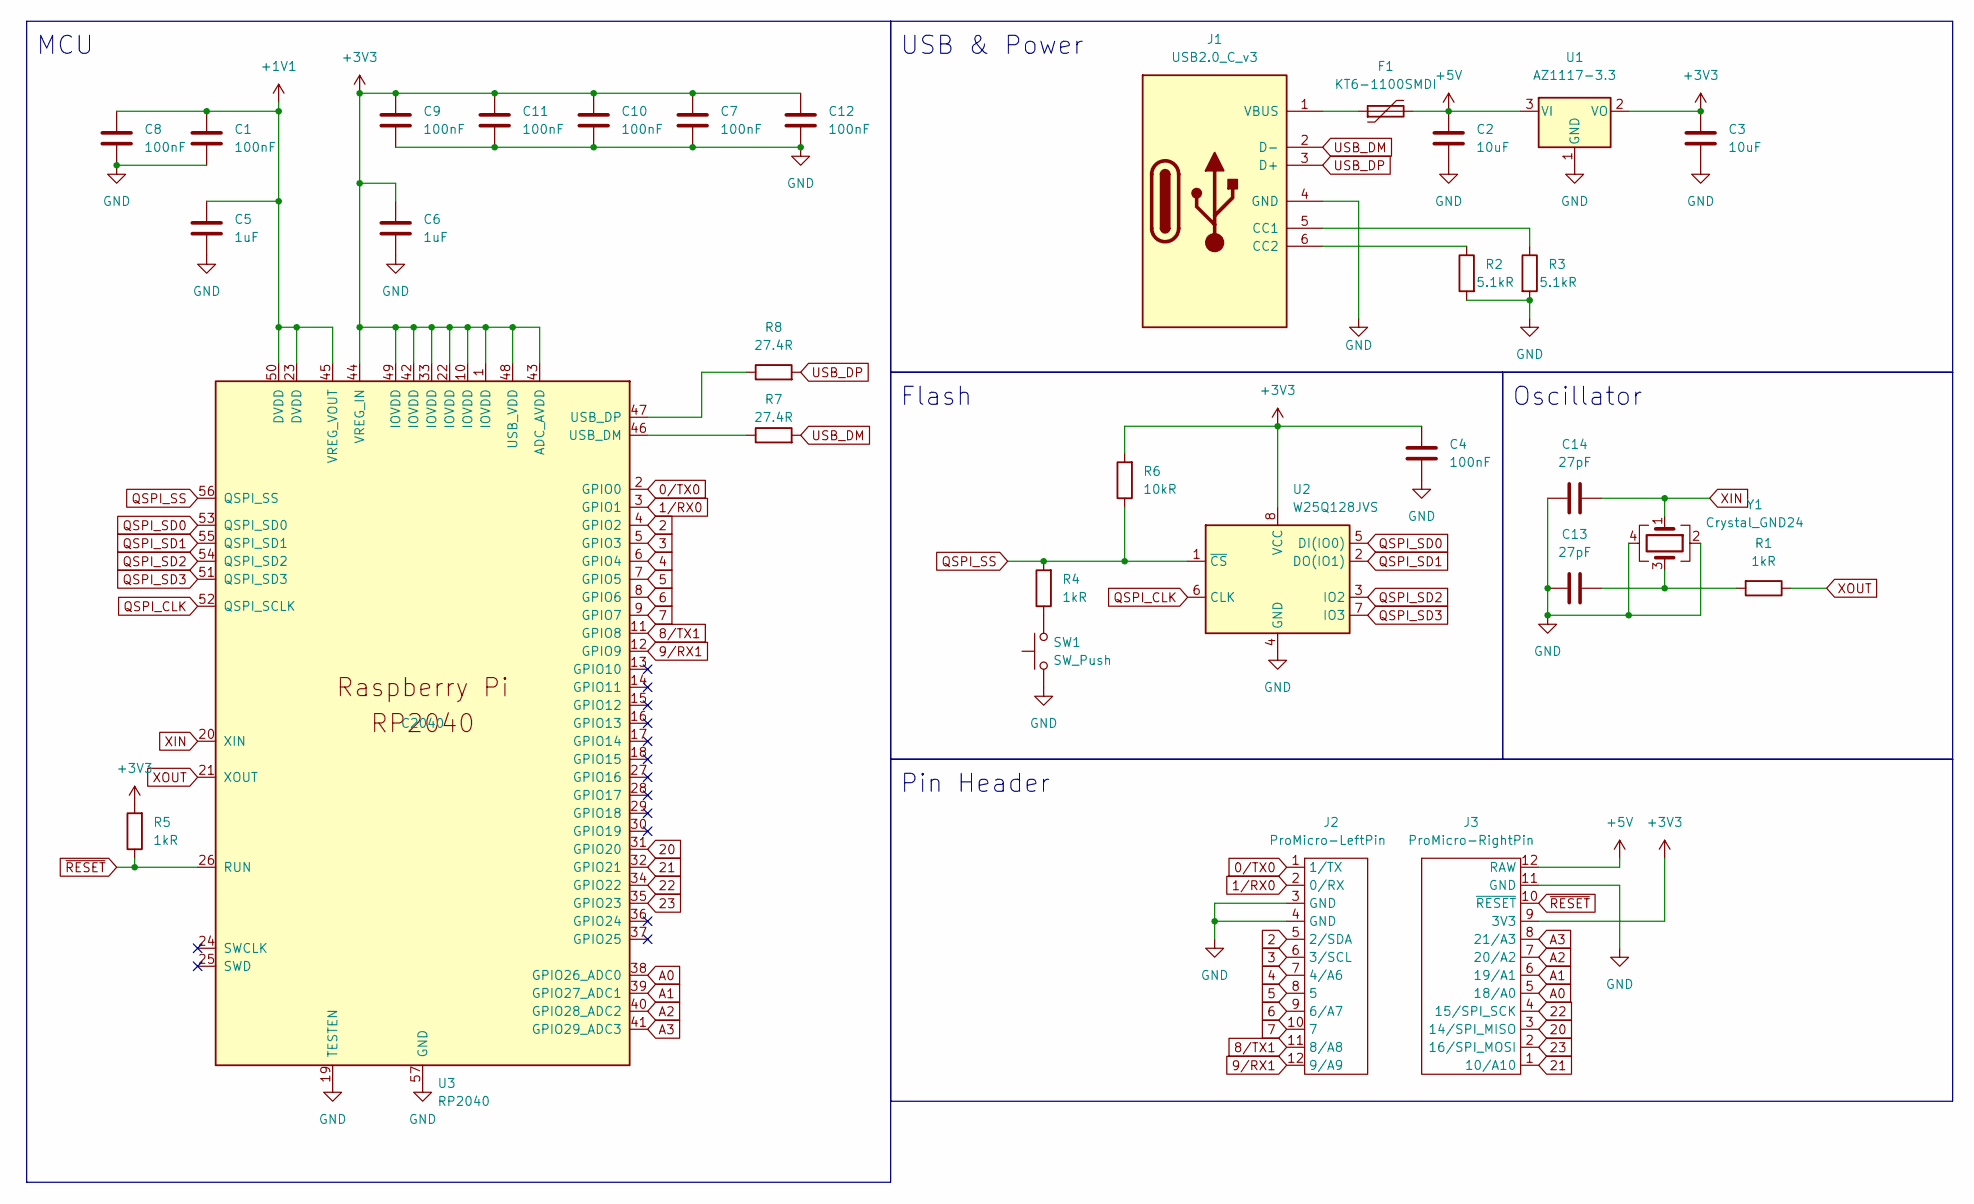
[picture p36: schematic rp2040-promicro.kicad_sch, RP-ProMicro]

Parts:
C1, C4, C7, C8, C9, C10, C11, C12: 100nF; Capacitor_0805_2012
C2, C3: 10uF; Capacitor_0805_2012
C5, C6: 1uF; Capacitor_0805_2012
C13, C14: 27pF; Capacitor_0805_2012
F1: KT6-1100SMDI; ResettableFuse_KT6-1100SMDI
J1: USB2.0_C_v3; USB-C-12-Pin-SMD
J2: ProMicro-LeftPin; ProMicro_LIKE_LEFT
J3: ProMicro-RightPin; ProMicro_LIKE_RIGHT
R1, R4, R5: 1kR; Register_0805_2012
R2, R3: 5.1kR; Register_0805_2012
R6: 10kR; Register_0805_2012
R7, R8: 27.4R; Register_0805_2012
SW1: SW_Push; SKRPABE010
U1: AZ1117-3.3; Regulator_AMS1117_SOT-89
U2: W25Q128JVS; W25Q16-128JV-SOIC
U3: RP2040; RP2040_hand; MPN C2040
Y1: Crystal_GND24; Crystal_SMD_3225-4Pin_3.2x2.5mm_HandSoldering

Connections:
0/TX0: J2.1 (1/TX), U3.2 (GPIO0)
1/RX0: J2.2 (0/RX), U3.3 (GPIO1)
2: J2.5 (2/SDA), U3.4 (GPIO2)
3: J2.6 (3/SCL), U3.5 (GPIO3)
4: J2.7 (4/A6), U3.6 (GPIO4)
5: J2.8 (5), U3.7 (GPIO5)
6: J2.9 (6/A7), U3.8 (GPIO6)
7: J2.10 (7), U3.9 (GPIO7)
8/TX1: J2.11 (8/A8), U3.11 (GPIO8)
9/RX1: J2.12 (9/A9), U3.12 (GPIO9)
20: J3.3 (14/SPI_MISO), U3.31 (GPIO20)
21: J3.1 (10/A10), U3.32 (GPIO21)
22: J3.4 (15/SPI_SCK), U3.34 (GPIO22)
23: J3.2 (16/SPI_MOSI), U3.35 (GPIO23)
+1V1: C1.1, C5.1, C8.1, U3.23 (DVDD), U3.45 (VREG_VOUT), U3.50 (DVDD)
+3V3: C3.1, C4.1, C6.1, C7.1, C9.1, C10.1, C11.1, C12.1, J3.9 (3V3), R5.2, R6.2, U1.2 (VO), U2.8 (VCC), U3.1 (IOVDD), U3.10 (IOVDD), U3.22 (IOVDD), U3.33 (IOVDD), U3.42 (IOVDD), U3.43 (ADC_AVDD), U3.44 (VREG_IN), U3.48 (USB_VDD), U3.49 (IOVDD)
+5V: C2.1, F1.2, J3.12 (RAW), U1.3 (VI)
A0: J3.5 (18/A0), U3.38 (GPIO26_ADC0)
A1: J3.6 (19/A1), U3.39 (GPIO27_ADC1)
A2: J3.7 (20/A2), U3.40 (GPIO28_ADC2)
A3: J3.8 (21/A3), U3.41 (GPIO29_ADC3)
GND: C1.2, C2.2, C3.2, C4.2, C5.2, C6.2, C7.2, C8.2, C9.2, C10.2, C11.2, C12.2, C13.1, C14.1, J1.4 (GND), J2.3 (GND), J2.4 (GND), J3.11 (GND), R2.2, R3.2, SW1.1, U1.1 (GND), U2.4 (GND), U3.19 (TESTEN), U3.57 (GND), Y1.2, Y1.4
unnamed: C13.2, R1.2, Y1.3
unnamed: F1.1, J1.1 (VBUS)
unnamed: J1.5 (CC1), R3.1
unnamed: J1.6 (CC2), R2.1
unnamed: R8.1, U3.47 (USB_DP)
unnamed: R7.1, U3.46 (USB_DM)
unnamed: R4.1, SW1.2
QSPI_CLK: U2.6 (CLK), U3.52 (QSPI_SCLK)
QSPI_SD0: U2.5 (DI(IO0)), U3.53 (QSPI_SD0)
QSPI_SD1: U2.2 (DO(IO1)), U3.55 (QSPI_SD1)
QSPI_SD2: U2.3 (IO2), U3.54 (QSPI_SD2)
QSPI_SD3: U2.7 (IO3), U3.51 (QSPI_SD3)
QSPI_SS: R4.2, R6.1, U2.1 (~CS), U3.56 (QSPI_SS)
USB_DM: J1.2 (D-), R7.2
USB_DP: J1.3 (D+), R8.2
XIN: C14.2, U3.20 (XIN), Y1.1
XOUT: R1.1, U3.21 (XOUT)
~RESET: J3.10 (~RESET), R5.1, U3.26 (RUN)

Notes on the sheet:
Pin Header
Flash
MCU
Oscillator
USB & Power

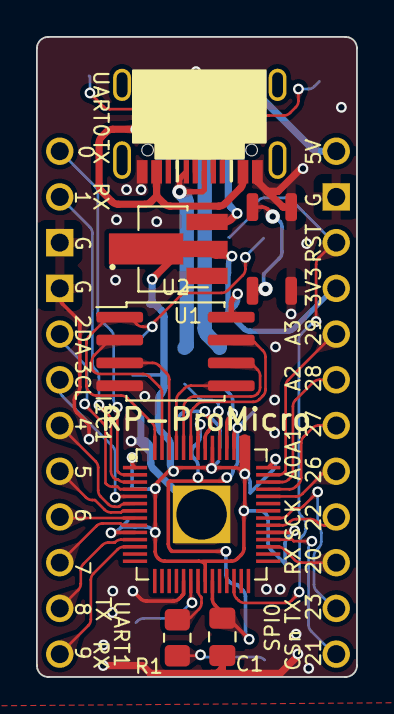
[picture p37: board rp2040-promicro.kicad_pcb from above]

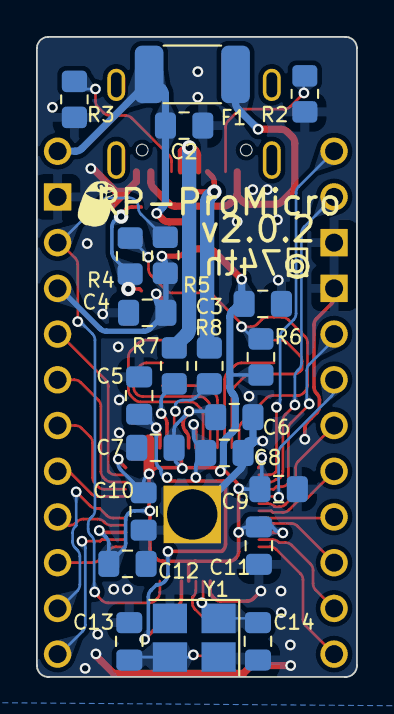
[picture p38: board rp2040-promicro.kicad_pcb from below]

Board: 2 copper layers, 17.8 x 35.6 mm, 31 parts (22 on the bottom side), 40 nets.

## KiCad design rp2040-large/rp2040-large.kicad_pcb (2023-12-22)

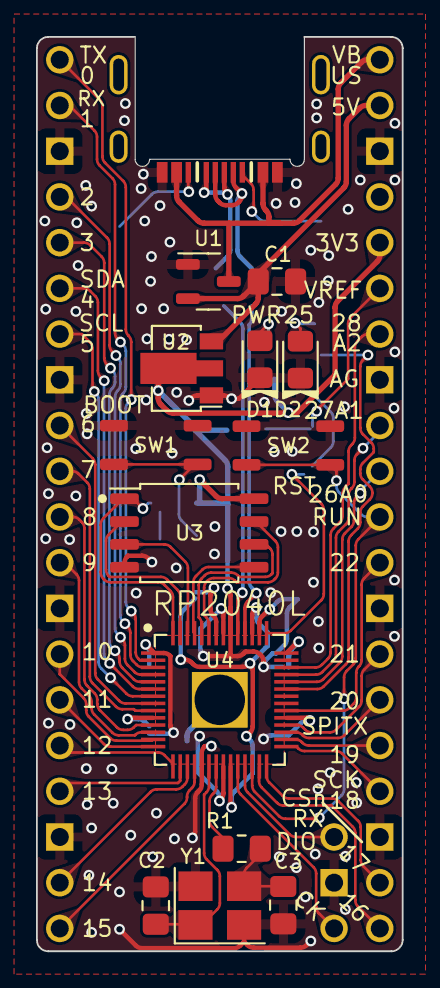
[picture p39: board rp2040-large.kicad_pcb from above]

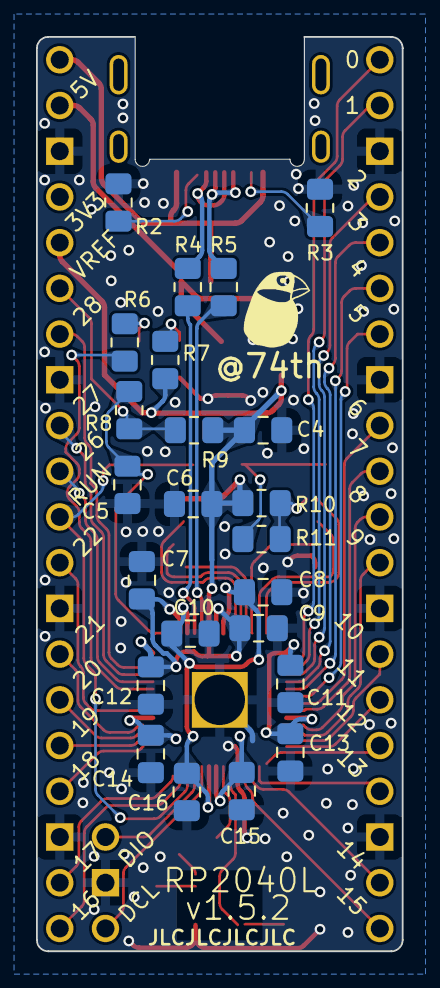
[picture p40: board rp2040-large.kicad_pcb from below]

Board: 2 copper layers, 20.3 x 50.8 mm, 41 parts (25 on the bottom side), 55 nets.

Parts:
C1, C4: 10uF; Capacitor_0805_2012
C2, C3: 27pF; Capacitor_0805_2012
C5, C7, C10: 1uF; Capacitor_0805_2012
C6, C8, C9, C11, C12, C13, C14, C15, C16: 100nF; Capacitor_0805_2012
CH1: RasperryPiPico PinOut; PinOut_RaspberryPiPico
CH2: SWD; PinOut_SWD_3Pin
D1: RED; LED_0805_2012
D2: BLUE; LED_0805_2012
J1: 217179-0001; Connector_USB-C-Receptacle_SMT_12-Pin_MidMount_Simple
MISC-ACCOUNTTEXT: Logo_74th_text
MISC-ICON: LOGO; Logo_74th_5mm
R1, R11: 1kR; Register_0805_2012
R2, R3: 5.1kR; Register_0805_2012
R4, R5: 27.4R; Register_0805_2012
R6: 10k; Register_0805_2012
R7: 5.1k; Register_0805_2012
R8: 1R; Register_0805_2012
R9: 200R; Register_0805_2012
R10: 10kR; Register_0805_2012
SW1, SW2: SW_Push; PushButton_SKRPABE010
U1: CH213K; Package_SOT-23
U2: AZ1117-3.3; Package_SOT-89-3
U3: W25Q32JVS; Package_SOIC-8_5.23x5.23mm_P1.27mm
U4: RP2040; Package_QFN-54-1EP_7x7mm_P0.4mm_EP3.1x3.1mm_hand
Y1: Crystal_GND24; Crystal_SMD_3225-4Pin_3.2x2.5mm_HandSoldering

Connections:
+1V1: C8.1, C10.1, C16.1, U4.23 (DVDD), U4.45 (VREG_VOUT), U4.50 (DVDD)
+3V3: C4.1, C6.1, C7.1, C9.1, C11.1, C12.1, C13.1, C14.1, C15.1, CH1.36 (3V3), R7.2, R9.2, R10.2, U2.2 (VO), U3.8 (VCC), U4.1 (IOVDD), U4.10 (IOVDD), U4.22 (IOVDD), U4.33 (IOVDD), U4.42 (IOVDD), U4.44 (VREG_IN), U4.48 (USB_VDD), U4.49 (IOVDD)
+5V: C1.1, CH1.39 (VSYS), U1.2 (VO-), U2.3 (VI)
/ADC_VREF: CH1.35 (VREF), R8.2, R9.1
/BOOTSEL: R11.1, SW1.2
/GPIO0: CH1.1 (0), U4.2 (GPIO0)
/GPIO1: CH1.2 (1), U4.3 (GPIO1)
/GPIO2: CH1.4 (2), U4.4 (GPIO2)
/GPIO3: CH1.5 (3), U4.5 (GPIO3)
/GPIO4: CH1.6 (4), U4.6 (GPIO4)
/GPIO5: CH1.7 (5), U4.7 (GPIO5)
/GPIO6: CH1.9 (6), U4.8 (GPIO6)
/GPIO7: CH1.10 (7), U4.9 (GPIO7)
/GPIO8: CH1.11 (8), U4.11 (GPIO8)
/GPIO9: CH1.12 (9), U4.12 (GPIO9)
/GPIO10: CH1.14 (10), U4.13 (GPIO10)
/GPIO11: CH1.15 (11), U4.14 (GPIO11)
/GPIO12: CH1.16 (12), U4.15 (GPIO12)
/GPIO13: CH1.17 (13), U4.16 (GPIO13)
/GPIO14: CH1.19 (14), U4.17 (GPIO14)
/GPIO15: CH1.20 (15), U4.18 (GPIO15)
/GPIO16: CH1.21 (16), U4.27 (GPIO16)
/GPIO17: CH1.22 (17), U4.28 (GPIO17)
/GPIO18: CH1.24 (18), U4.29 (GPIO18)
/GPIO19: CH1.25 (19), U4.30 (GPIO19)
/GPIO20: CH1.26 (20), U4.31 (GPIO20)
/GPIO21: CH1.27 (21), U4.32 (GPIO21)
/GPIO22: CH1.29 (22), U4.34 (GPIO22)
/GPIO26: CH1.31 (26), U4.38 (GPIO26_ADC0)
/GPIO27: CH1.32 (27), U4.39 (GPIO27_ADC1)
/GPIO28: CH1.34 (28), U4.40 (GPIO28_ADC2)
/LED: D2.2 (A), R6.2
/QSPI_CLK: U3.6 (CLK), U4.52 (QSPI_SCLK)
/QSPI_SD0: U3.5 (DI(IO0)), U4.53 (QSPI_SD0)
/QSPI_SD1: U3.2 (DO(IO1)), U4.55 (QSPI_SD1)
/QSPI_SD2: U3.3 (IO2), U4.54 (QSPI_SD2)
/QSPI_SD3: U3.7 (IO3), U4.51 (QSPI_SD3)
/QSPI_SS: R10.1, R11.2, U3.1 (~CS), U4.56 (QSPI_SS)
/RUN: CH1.30 (RUN), SW2.2, U4.26 (RUN)
/SWCLK: CH2.1 (SWCLK), U4.24 (SWCLK)
/SWDIO: CH2.3 (SWDIO), U4.25 (SWD)
/USB_DM: R4.2, U4.46 (USB_DM)
/USB_DP: R5.2, U4.47 (USB_DP)
/XIN: C2.2, U4.20 (XIN), Y1.1
/XOUT: R1.1, U4.21 (XOUT)
GND: C1.2, C2.1, C3.1, C4.2, C5.2, C6.2, C7.2, C8.2, C9.2, C10.2, C11.2, C12.2, C13.2, C14.2, C15.2, C16.2, CH1.3 (GND), CH1.8 (GND), CH1.13 (GND), CH1.18 (GND), CH1.23 (GND), CH1.28 (GND), CH1.33 (GND), CH1.38 (GND), CH2.2 (GND), D1.1 (K), D2.1 (K), J1.4 (GND), R2.2, R3.2, SW1.1, SW2.1, U1.1 (GND), U2.1 (GND), U3.4 (GND), U4.19 (TESTEN), U4.57 (GND), Y1.2, Y1.4
unnamed: C3.2, R1.2, Y1.3
unnamed: D1.2 (A), R7.1
unnamed: J1.5 (CC1), R2.1
unnamed: J1.6 (CC2), R3.1
unnamed: J1.3 (D+), R5.1
unnamed: J1.2 (D-), R4.1
unnamed: C5.1, R8.1, U4.43 (ADC_AVDD)
unnamed: R6.1, U4.37 (GPIO25)
VBUS: CH1.40 (VBUS), J1.1 (VBUS), U1.3 (VI+)

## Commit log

2022-07-11 pro micro board
    [rp2040-promicro.kicad_pcb, rp2040-promicro.kicad_sch]
2022-07-11 update BOM
2022-08-27 rp2040-large v1.4.0
    [rp2040-large-support.kicad_pcb, rp2040-large.kicad_pcb, rp2040-large.kicad_sch]
2022-12-31 promicro v2
    [rp2040-promicro.kicad_pcb, rp2040-promicro.kicad_sch]
2023-01-01 update datasheet
    [rp2040-large.csv]
2023-01-01 rp-promicro v2.0.0
    [rp2040-promicro.kicad_pcb]
2023-01-15 古い記述を削除
2023-09-17 v2.0.1で最後に位置を整列したのが未コミットだった
    [rp2040-promicro.kicad_pcb, rp2040-promicro.kicad_sch]
2023-09-17 fix BOM
2023-09-18 fix v2.0.1
    [rp2040-promicro.kicad_sch]
2024-09-15 add pin map
2024-09-15 pin map
